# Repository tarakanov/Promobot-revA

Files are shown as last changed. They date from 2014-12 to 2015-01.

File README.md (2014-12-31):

Promobot
=============

Main board for Promobot, robotic platform. Still in development.

Schematic and layout done in Eagle.
Board has four VNH5019A-E H-bridge drivers for high current DC brushed motors, 50W 2ch audio amplifier (TPA116D2), two DC/DC step-up converters (TPS43061, up to 40V, 20A), one DC/DC step-down converter (TPS563200, 5V, 3A) and MCU for control (atmega32u4, Arduino Leonardo compatible).

It is initial design, so the board is big and bulky (15x15 cm). The board is manufactured and tested, but the current and power limits was not reached. There is a lot things to cut. Feel free to ask questions and make improvements.

Designed by Semyon Tarakanov. Creative Commons Attribution, Share-Alike license.

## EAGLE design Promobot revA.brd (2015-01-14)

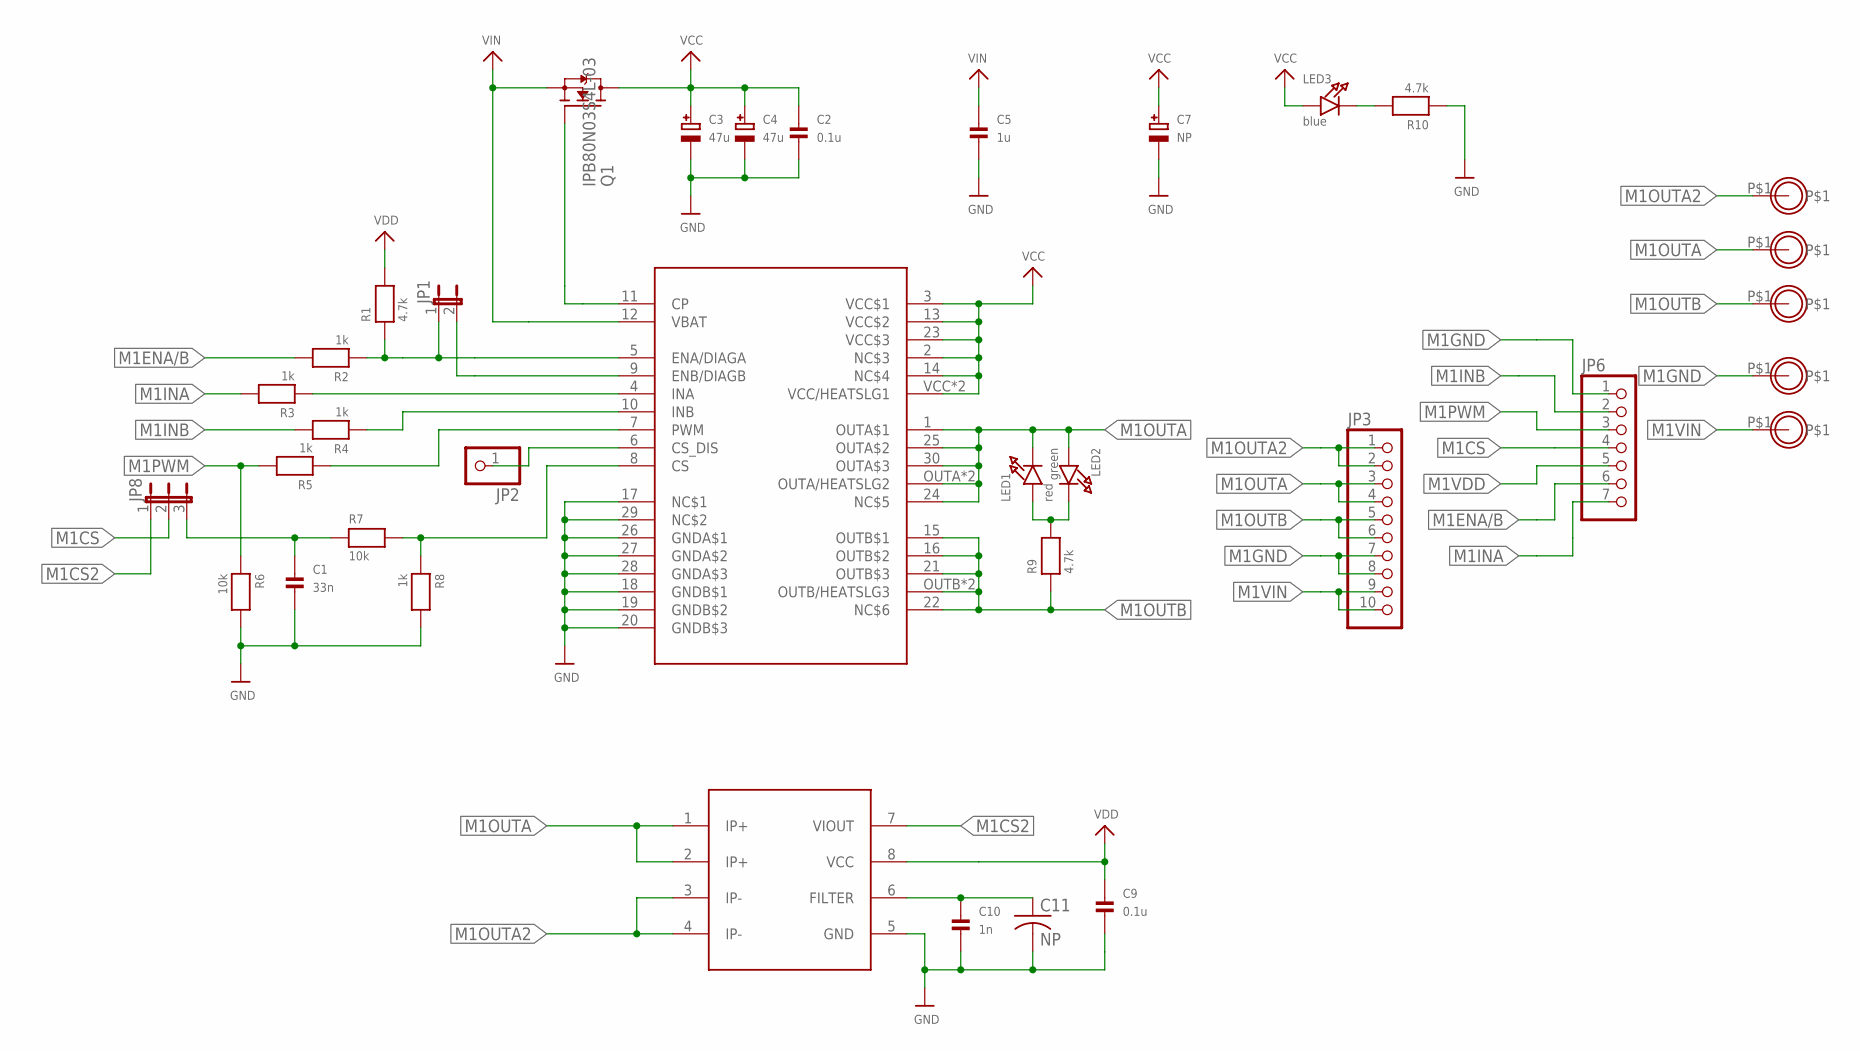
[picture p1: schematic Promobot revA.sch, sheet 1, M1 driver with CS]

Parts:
C1: 33n; _0603
C2, C9: 0.1u; _0603
C3, C4: 47u; PANASONIC_C
C5: 1u; _0805
C7: NP; CELEC_3.5MM_10MM
C10: 1n; _0603
C11: NP; C025-024X044
JP1: JUMPER2
JP2: HEADER-1X1ROUND; 1X01_ROUND
JP3: HEADER-1X10ROUND; 1X10_ROUND
JP6: HEADER-1X7ROUND; 1X07_ROUND
JP8: JUMPER3
LED1: red; CHIPLED_0603
LED2: green; CHIPLED_0603
LED3: blue; CHIPLED_0603
M1OUTA, M1OUTA1, M1OUTA3, M1OUTA4, M1OUTB: MOUNTINGHOLE2.5_THICK; MOUNTINGHOLE_2.5_PLATED_THICK
Q1: IPB80N03S4L-03; TO263
R1, R9, R10: 4.7k; 0603
R2, R3, R4, R5, R8: 1k; 0603
R6, R7: 10k; 0603
U1: VNH5019A-E; MULTIPOWERSO-30
U2: ACS714; SOIC8_208MIL

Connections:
M1CS: JP6.4, JP8.2
M1CS1: C1.1, JP8.3, R7.1
M1CS2: JP8.1, U2.7 (VIOUT)
M1ENA/B: JP6.6, R2.2
M1GND: C1.2, C2.2, C3.-, C4.-, C5.2, C7.-, C9.2, C10.2, C11.2, JP3.7, JP3.8, JP6.1, M1OUTA3.P$1, R6.2, R8.2, R10.1, U1.17 (NC$1), U1.18 (GNDB$1), U1.19 (GNDB$2), U1.20 (GNDB$3), U1.26 (GNDA$1), U1.27 (GNDA$2), U1.28 (GNDA$3), U1.29 (NC$2), U2.5 (GND); also elsewhere on the board
M1INA: JP6.7, R3.2
M1INB: JP6.2, R4.2
M1OUTA: JP3.3, JP3.4, LED1.C, LED2.A, M1OUTA1.P$1, U1.1 (OUTA$1), U1.24 (NC$5), U1.25 (OUTA$2), U1.30 (OUTA$3), U1.OUTA (OUTA/HEATSLG2), U1.OUTA@1 (OUTA/HEATSLG2), U2.1 (IP+), U2.2 (IP+)
M1OUTA2: JP3.1, JP3.2, M1OUTA.P$1, U2.3 (IP-), U2.4 (IP-)
M1OUTB: JP3.5, JP3.6, M1OUTB.P$1, R9.1, U1.15 (OUTB$1), U1.16 (OUTB$2), U1.21 (OUTB$3), U1.22 (NC$6), U1.OUTB (OUTB/HEATSLG3), U1.OUTB@1 (OUTB/HEATSLG3)
M1PWM: JP6.3, R5.2, R6.1
M1VCC: C2.1, C3.+, C4.+, C7.+, LED3.A, Q1.3 (D), U1.2 (NC$3), U1.3 (VCC$1), U1.13 (VCC$2), U1.14 (NC$4), U1.23 (VCC$3), U1.VCC (VCC/HEATSLG1), U1.VCC@1 (VCC/HEATSLG1); also elsewhere on the board
M1VDD: C9.1, JP6.5, R1.2, U2.8 (VCC)
M1VIN: C5.1, JP3.9, JP3.10, M1OUTA4.P$1, Q1.2 (S), U1.12 (VBAT)
unnamed: Q1.1 (G), U1.11 (CP)
unnamed: JP1.2, U1.9 (ENB/DIAGB)
unnamed: R5.1, U1.7 (PWM)
unnamed: JP1.1, R1.1, R2.1, U1.5 (ENA/DIAGA)
unnamed: R7.2, R8.1, U1.8 (CS)
unnamed: R3.1, U1.4 (INA)
unnamed: R4.1, U1.10 (INB)
unnamed: JP2.1, U1.6 (CS_DIS)
unnamed: LED3.C, R10.2
unnamed: C10.1, C11.1, U2.6 (FILTER)
unnamed: LED1.A, LED2.C, R9.2

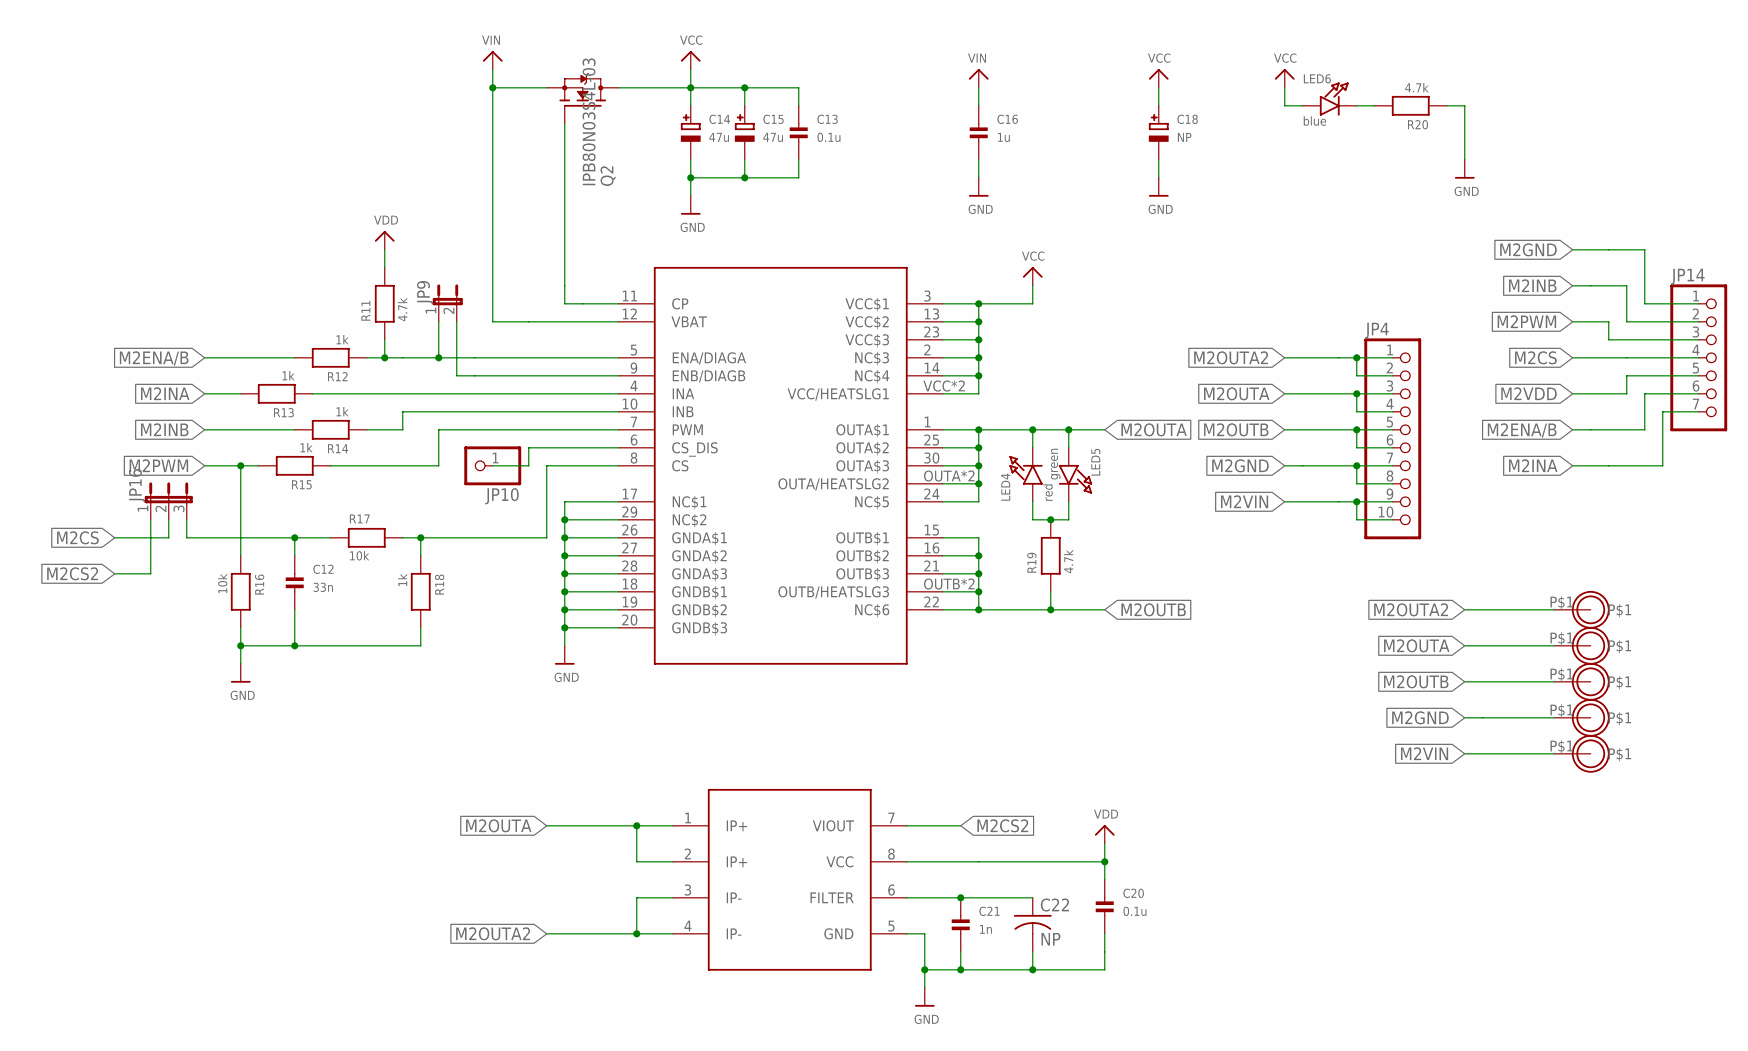
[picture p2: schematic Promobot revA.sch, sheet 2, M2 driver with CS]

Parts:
C12: 33n; _0603
C13, C20: 0.1u; _0603
C14, C15: 47u; PANASONIC_C
C16: 1u; _0805
C18: NP; CELEC_3.5MM_10MM
C21: 1n; _0603
C22: NP; C025-024X044
JP4: HEADER-1X10ROUND; 1X10_ROUND
JP9: JUMPER2
JP10: HEADER-1X1ROUND; 1X01_ROUND
JP14: HEADER-1X7ROUND; 1X07_ROUND
JP16: JUMPER3
LED4: red; CHIPLED_0603
LED5: green; CHIPLED_0603
LED6: blue; CHIPLED_0603
M1OUTA2, M1OUTA5, M1OUTA6, M1OUTA7, M1OUTB1: MOUNTINGHOLE2.5_THICK; MOUNTINGHOLE_2.5_PLATED_THICK
Q2: IPB80N03S4L-03; TO263
R11, R19, R20: 4.7k; 0603
R12, R13, R14, R15, R18: 1k; 0603
R16, R17: 10k; 0603
U3: VNH5019A-E; MULTIPOWERSO-30
U4: ACS714; SOIC8_208MIL

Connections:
M2CS: JP14.4, JP16.2
M2CS2: JP16.1, U4.7 (VIOUT)
M2ENA/B: JP14.6, R12.2
M2GND: C12.2, C13.2, C14.-, C15.-, C16.2, C18.-, C20.2, C21.2, C22.2, JP4.7, JP4.8, JP14.1, M1OUTA6.P$1, R16.2, R18.2, R20.1, U3.17 (NC$1), U3.18 (GNDB$1), U3.19 (GNDB$2), U3.20 (GNDB$3), U3.26 (GNDA$1), U3.27 (GNDA$2), U3.28 (GNDA$3), U3.29 (NC$2), U4.5 (GND); also elsewhere on the board
M2INA: JP14.7, R13.2
M2INB: JP14.2, R14.2
M2OUTA: JP4.3, JP4.4, LED4.C, LED5.A, M1OUTA5.P$1, U3.1 (OUTA$1), U3.24 (NC$5), U3.25 (OUTA$2), U3.30 (OUTA$3), U3.OUTA (OUTA/HEATSLG2), U3.OUTA@1 (OUTA/HEATSLG2), U4.1 (IP+), U4.2 (IP+)
M2OUTA2: JP4.1, JP4.2, M1OUTA2.P$1, U4.3 (IP-), U4.4 (IP-)
M2OUTB: JP4.5, JP4.6, M1OUTB1.P$1, R19.1, U3.15 (OUTB$1), U3.16 (OUTB$2), U3.21 (OUTB$3), U3.22 (NC$6), U3.OUTB (OUTB/HEATSLG3), U3.OUTB@1 (OUTB/HEATSLG3)
M2PWM: JP14.3, R15.2, R16.1
M2VCC: C13.1, C14.+, C15.+, C18.+, LED6.A, Q2.3 (D), U3.2 (NC$3), U3.3 (VCC$1), U3.13 (VCC$2), U3.14 (NC$4), U3.23 (VCC$3), U3.VCC (VCC/HEATSLG1), U3.VCC@1 (VCC/HEATSLG1); also elsewhere on the board
M2VDD: C20.1, JP14.5, R11.2, U4.8 (VCC)
M2VIN: C16.1, JP4.9, JP4.10, M1OUTA7.P$1, Q2.2 (S), U3.12 (VBAT)
unnamed: Q2.1 (G), U3.11 (CP)
unnamed: JP9.1, R11.1, R12.1, U3.5 (ENA/DIAGA)
unnamed: JP9.2, U3.9 (ENB/DIAGB)
unnamed: R13.1, U3.4 (INA)
unnamed: R14.1, U3.10 (INB)
unnamed: R15.1, U3.7 (PWM)
unnamed: R17.2, R18.1, U3.8 (CS)
unnamed: JP10.1, U3.6 (CS_DIS)
unnamed: LED4.A, LED5.C, R19.2
unnamed: LED6.C, R20.2
unnamed: C21.1, C22.1, U4.6 (FILTER)
unnamed: C12.1, JP16.3, R17.1

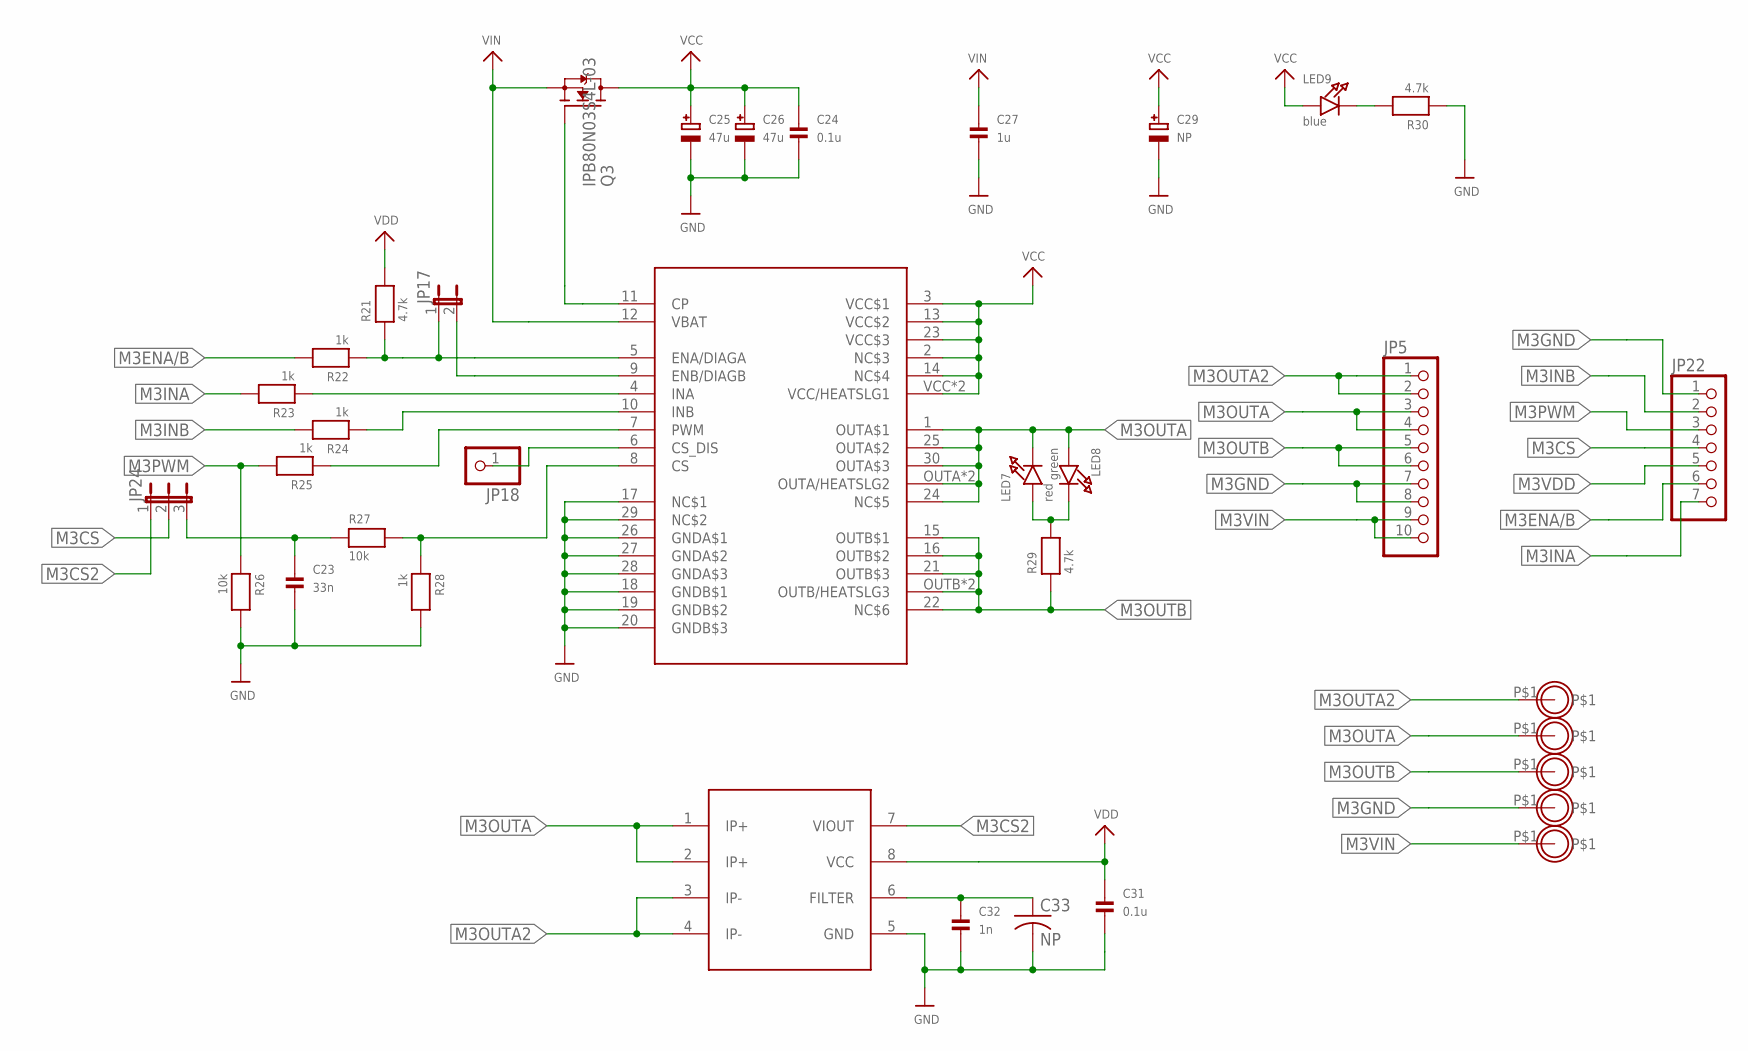
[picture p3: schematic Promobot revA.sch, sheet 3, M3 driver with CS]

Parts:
C23: 33n; _0603
C24, C31: 0.1u; _0603
C25, C26: 47u; PANASONIC_C
C27: 1u; _0805
C29: NP; CELEC_3.5MM_10MM
C32: 1n; _0603
C33: NP; C025-024X044
JP5: HEADER-1X10ROUND; 1X10_ROUND
JP17: JUMPER2
JP18: HEADER-1X1ROUND; 1X01_ROUND
JP22: HEADER-1X7ROUND; 1X07_ROUND
JP24: JUMPER3
LED7: red; CHIPLED_0603
LED8: green; CHIPLED_0603
LED9: blue; CHIPLED_0603
M1OUTA8, M1OUTA9, M1OUTA10, M1OUTA11, M1OUTB2: MOUNTINGHOLE2.5_THICK; MOUNTINGHOLE_2.5_PLATED_THICK
Q3: IPB80N03S4L-03; TO263
R21, R29, R30: 4.7k; 0603
R22, R23, R24, R25, R28: 1k; 0603
R26, R27: 10k; 0603
U5: VNH5019A-E; MULTIPOWERSO-30
U6: ACS714; SOIC8_208MIL

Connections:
M3CS: JP22.4, JP24.2
M3CS2: JP24.1, U6.7 (VIOUT)
M3ENA/B: JP22.6, R22.2
M3GND: C23.2, C24.2, C25.-, C26.-, C27.2, C29.-, C31.2, C32.2, C33.2, JP5.7, JP5.8, JP22.1, M1OUTA10.P$1, R26.2, R28.2, R30.1, U5.17 (NC$1), U5.18 (GNDB$1), U5.19 (GNDB$2), U5.20 (GNDB$3), U5.26 (GNDA$1), U5.27 (GNDA$2), U5.28 (GNDA$3), U5.29 (NC$2), U6.5 (GND); also elsewhere on the board
M3INA: JP22.7, R23.2
M3INB: JP22.2, R24.2
M3OUTA: JP5.3, JP5.4, LED7.C, LED8.A, M1OUTA9.P$1, U5.1 (OUTA$1), U5.24 (NC$5), U5.25 (OUTA$2), U5.30 (OUTA$3), U5.OUTA (OUTA/HEATSLG2), U5.OUTA@1 (OUTA/HEATSLG2), U6.1 (IP+), U6.2 (IP+)
M3OUTA2: JP5.1, JP5.2, M1OUTA8.P$1, U6.3 (IP-), U6.4 (IP-)
M3OUTB: JP5.5, JP5.6, M1OUTB2.P$1, R29.1, U5.15 (OUTB$1), U5.16 (OUTB$2), U5.21 (OUTB$3), U5.22 (NC$6), U5.OUTB (OUTB/HEATSLG3), U5.OUTB@1 (OUTB/HEATSLG3)
M3PWM: JP22.3, R25.2, R26.1
M3VCC: C24.1, C25.+, C26.+, C29.+, LED9.A, Q3.3 (D), U5.2 (NC$3), U5.3 (VCC$1), U5.13 (VCC$2), U5.14 (NC$4), U5.23 (VCC$3), U5.VCC (VCC/HEATSLG1), U5.VCC@1 (VCC/HEATSLG1); also elsewhere on the board
M3VDD: C31.1, JP22.5, R21.2, U6.8 (VCC)
M3VIN: C27.1, JP5.9, JP5.10, M1OUTA11.P$1, Q3.2 (S), U5.12 (VBAT)
unnamed: Q3.1 (G), U5.11 (CP)
unnamed: JP17.1, R21.1, R22.1, U5.5 (ENA/DIAGA)
unnamed: JP17.2, U5.9 (ENB/DIAGB)
unnamed: R23.1, U5.4 (INA)
unnamed: R24.1, U5.10 (INB)
unnamed: R25.1, U5.7 (PWM)
unnamed: R27.2, R28.1, U5.8 (CS)
unnamed: JP18.1, U5.6 (CS_DIS)
unnamed: LED7.A, LED8.C, R29.2
unnamed: LED9.C, R30.2
unnamed: C32.1, C33.1, U6.6 (FILTER)
unnamed: C23.1, JP24.3, R27.1

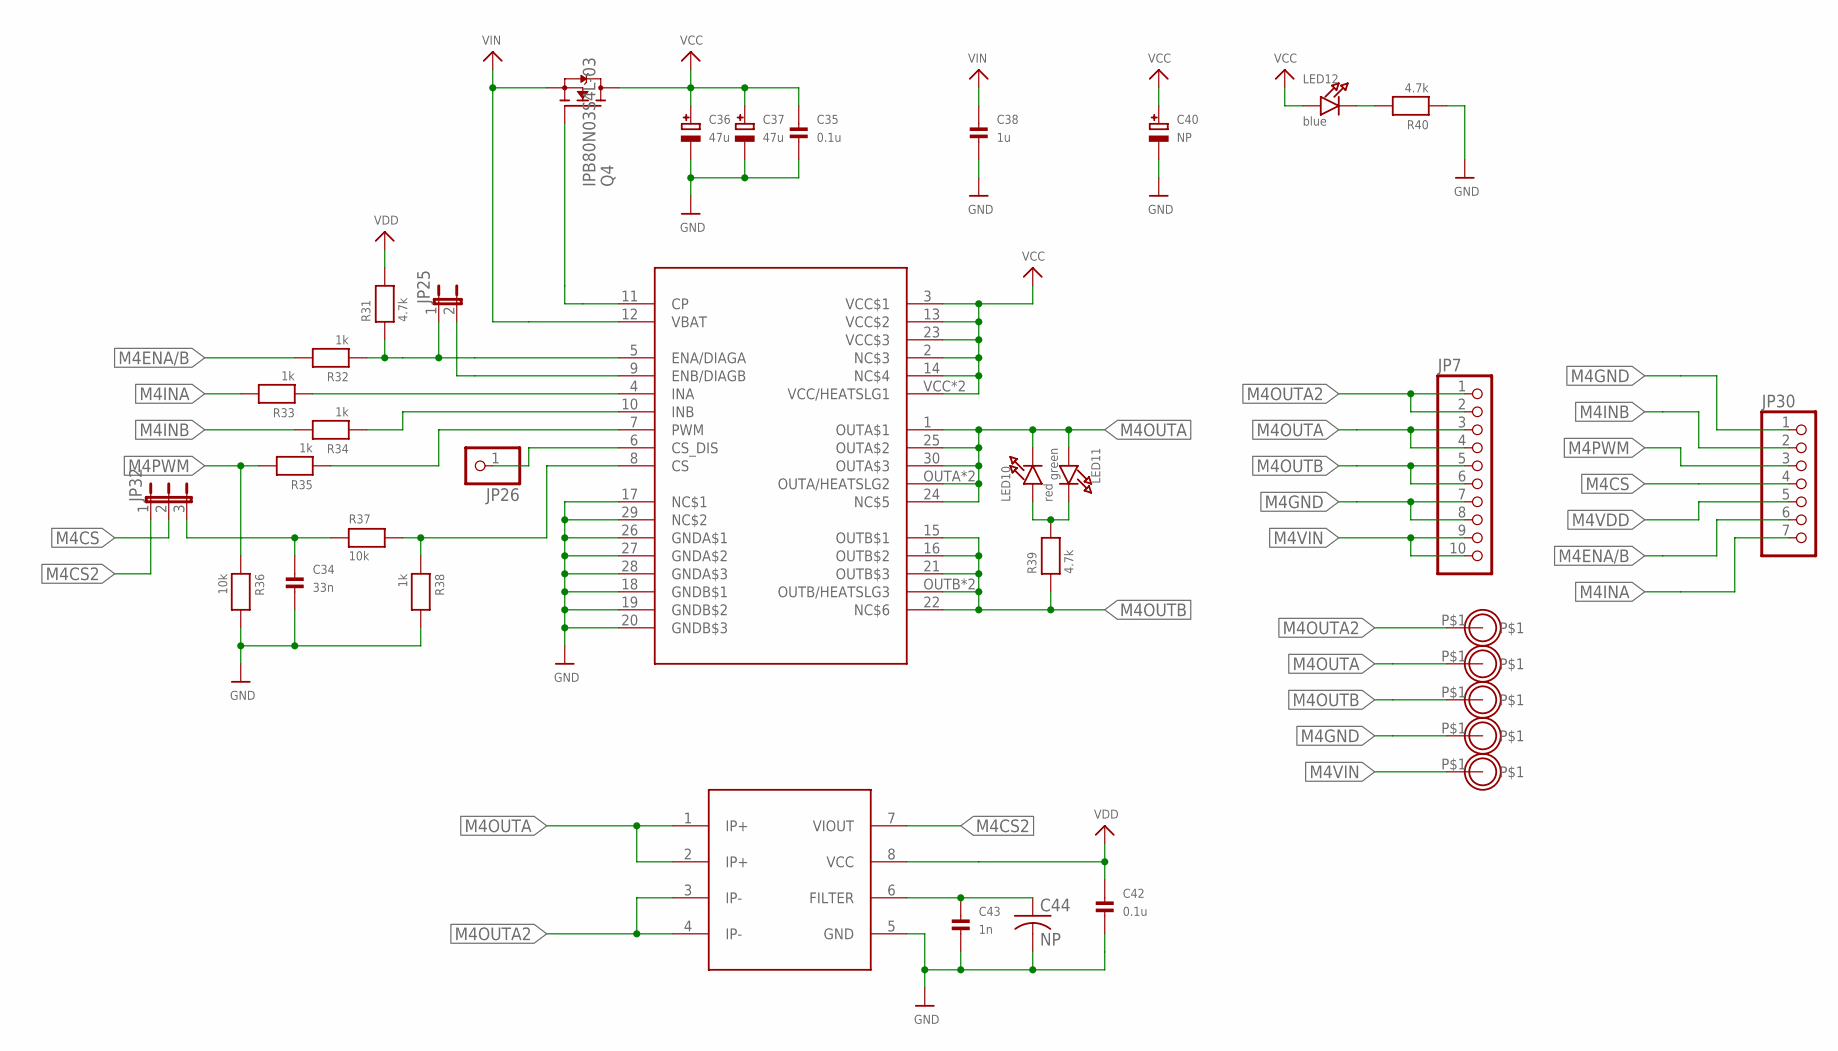
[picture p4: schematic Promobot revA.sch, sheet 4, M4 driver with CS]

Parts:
C34: 33n; _0603
C35, C42: 0.1u; _0603
C36, C37: 47u; PANASONIC_C
C38: 1u; _0805
C40: NP; CELEC_3.5MM_10MM
C43: 1n; _0603
C44: NP; C025-024X044
JP7: HEADER-1X10ROUND; 1X10_ROUND
JP25: JUMPER2
JP26: HEADER-1X1ROUND; 1X01_ROUND
JP30: HEADER-1X7ROUND; 1X07_ROUND
JP32: JUMPER3
LED10: red; CHIPLED_0603
LED11: green; CHIPLED_0603
LED12: blue; CHIPLED_0603
M1OUTA12, M1OUTA13, M1OUTA14, M1OUTA15, M1OUTB3: MOUNTINGHOLE2.5_THICK; MOUNTINGHOLE_2.5_PLATED_THICK
Q4: IPB80N03S4L-03; TO263
R31, R39, R40: 4.7k; 0603
R32, R33, R34, R35, R38: 1k; 0603
R36, R37: 10k; 0603
U7: VNH5019A-E; MULTIPOWERSO-30
U8: ACS714; SOIC8_208MIL

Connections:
M4CS: JP30.4, JP32.2
M4CS2: JP32.1, U8.7 (VIOUT)
M4ENA/B: JP30.6, R32.2
M4GND: C34.2, C35.2, C36.-, C37.-, C38.2, C40.-, C42.2, C43.2, C44.2, JP7.7, JP7.8, JP30.1, M1OUTA14.P$1, R36.2, R38.2, R40.1, U7.17 (NC$1), U7.18 (GNDB$1), U7.19 (GNDB$2), U7.20 (GNDB$3), U7.26 (GNDA$1), U7.27 (GNDA$2), U7.28 (GNDA$3), U7.29 (NC$2), U8.5 (GND); also elsewhere on the board
M4INA: JP30.7, R33.2
M4INB: JP30.2, R34.2
M4OUTA: JP7.3, JP7.4, LED10.C, LED11.A, M1OUTA13.P$1, U7.1 (OUTA$1), U7.24 (NC$5), U7.25 (OUTA$2), U7.30 (OUTA$3), U7.OUTA (OUTA/HEATSLG2), U7.OUTA@1 (OUTA/HEATSLG2), U8.1 (IP+), U8.2 (IP+)
M4OUTA2: JP7.1, JP7.2, M1OUTA12.P$1, U8.3 (IP-), U8.4 (IP-)
M4OUTB: JP7.5, JP7.6, M1OUTB3.P$1, R39.1, U7.15 (OUTB$1), U7.16 (OUTB$2), U7.21 (OUTB$3), U7.22 (NC$6), U7.OUTB (OUTB/HEATSLG3), U7.OUTB@1 (OUTB/HEATSLG3)
M4PWM: JP30.3, R35.2, R36.1
M4VCC: C35.1, C36.+, C37.+, C40.+, LED12.A, Q4.3 (D), U7.2 (NC$3), U7.3 (VCC$1), U7.13 (VCC$2), U7.14 (NC$4), U7.23 (VCC$3), U7.VCC (VCC/HEATSLG1), U7.VCC@1 (VCC/HEATSLG1); also elsewhere on the board
M4VDD: C42.1, JP30.5, R31.2, U8.8 (VCC)
M4VIN: C38.1, JP7.9, JP7.10, M1OUTA15.P$1, Q4.2 (S), U7.12 (VBAT)
unnamed: Q4.1 (G), U7.11 (CP)
unnamed: JP25.1, R31.1, R32.1, U7.5 (ENA/DIAGA)
unnamed: JP25.2, U7.9 (ENB/DIAGB)
unnamed: R33.1, U7.4 (INA)
unnamed: R34.1, U7.10 (INB)
unnamed: R35.1, U7.7 (PWM)
unnamed: R37.2, R38.1, U7.8 (CS)
unnamed: JP26.1, U7.6 (CS_DIS)
unnamed: LED10.A, LED11.C, R39.2
unnamed: LED12.C, R40.2
unnamed: C43.1, C44.1, U8.6 (FILTER)
unnamed: C34.1, JP32.3, R37.1

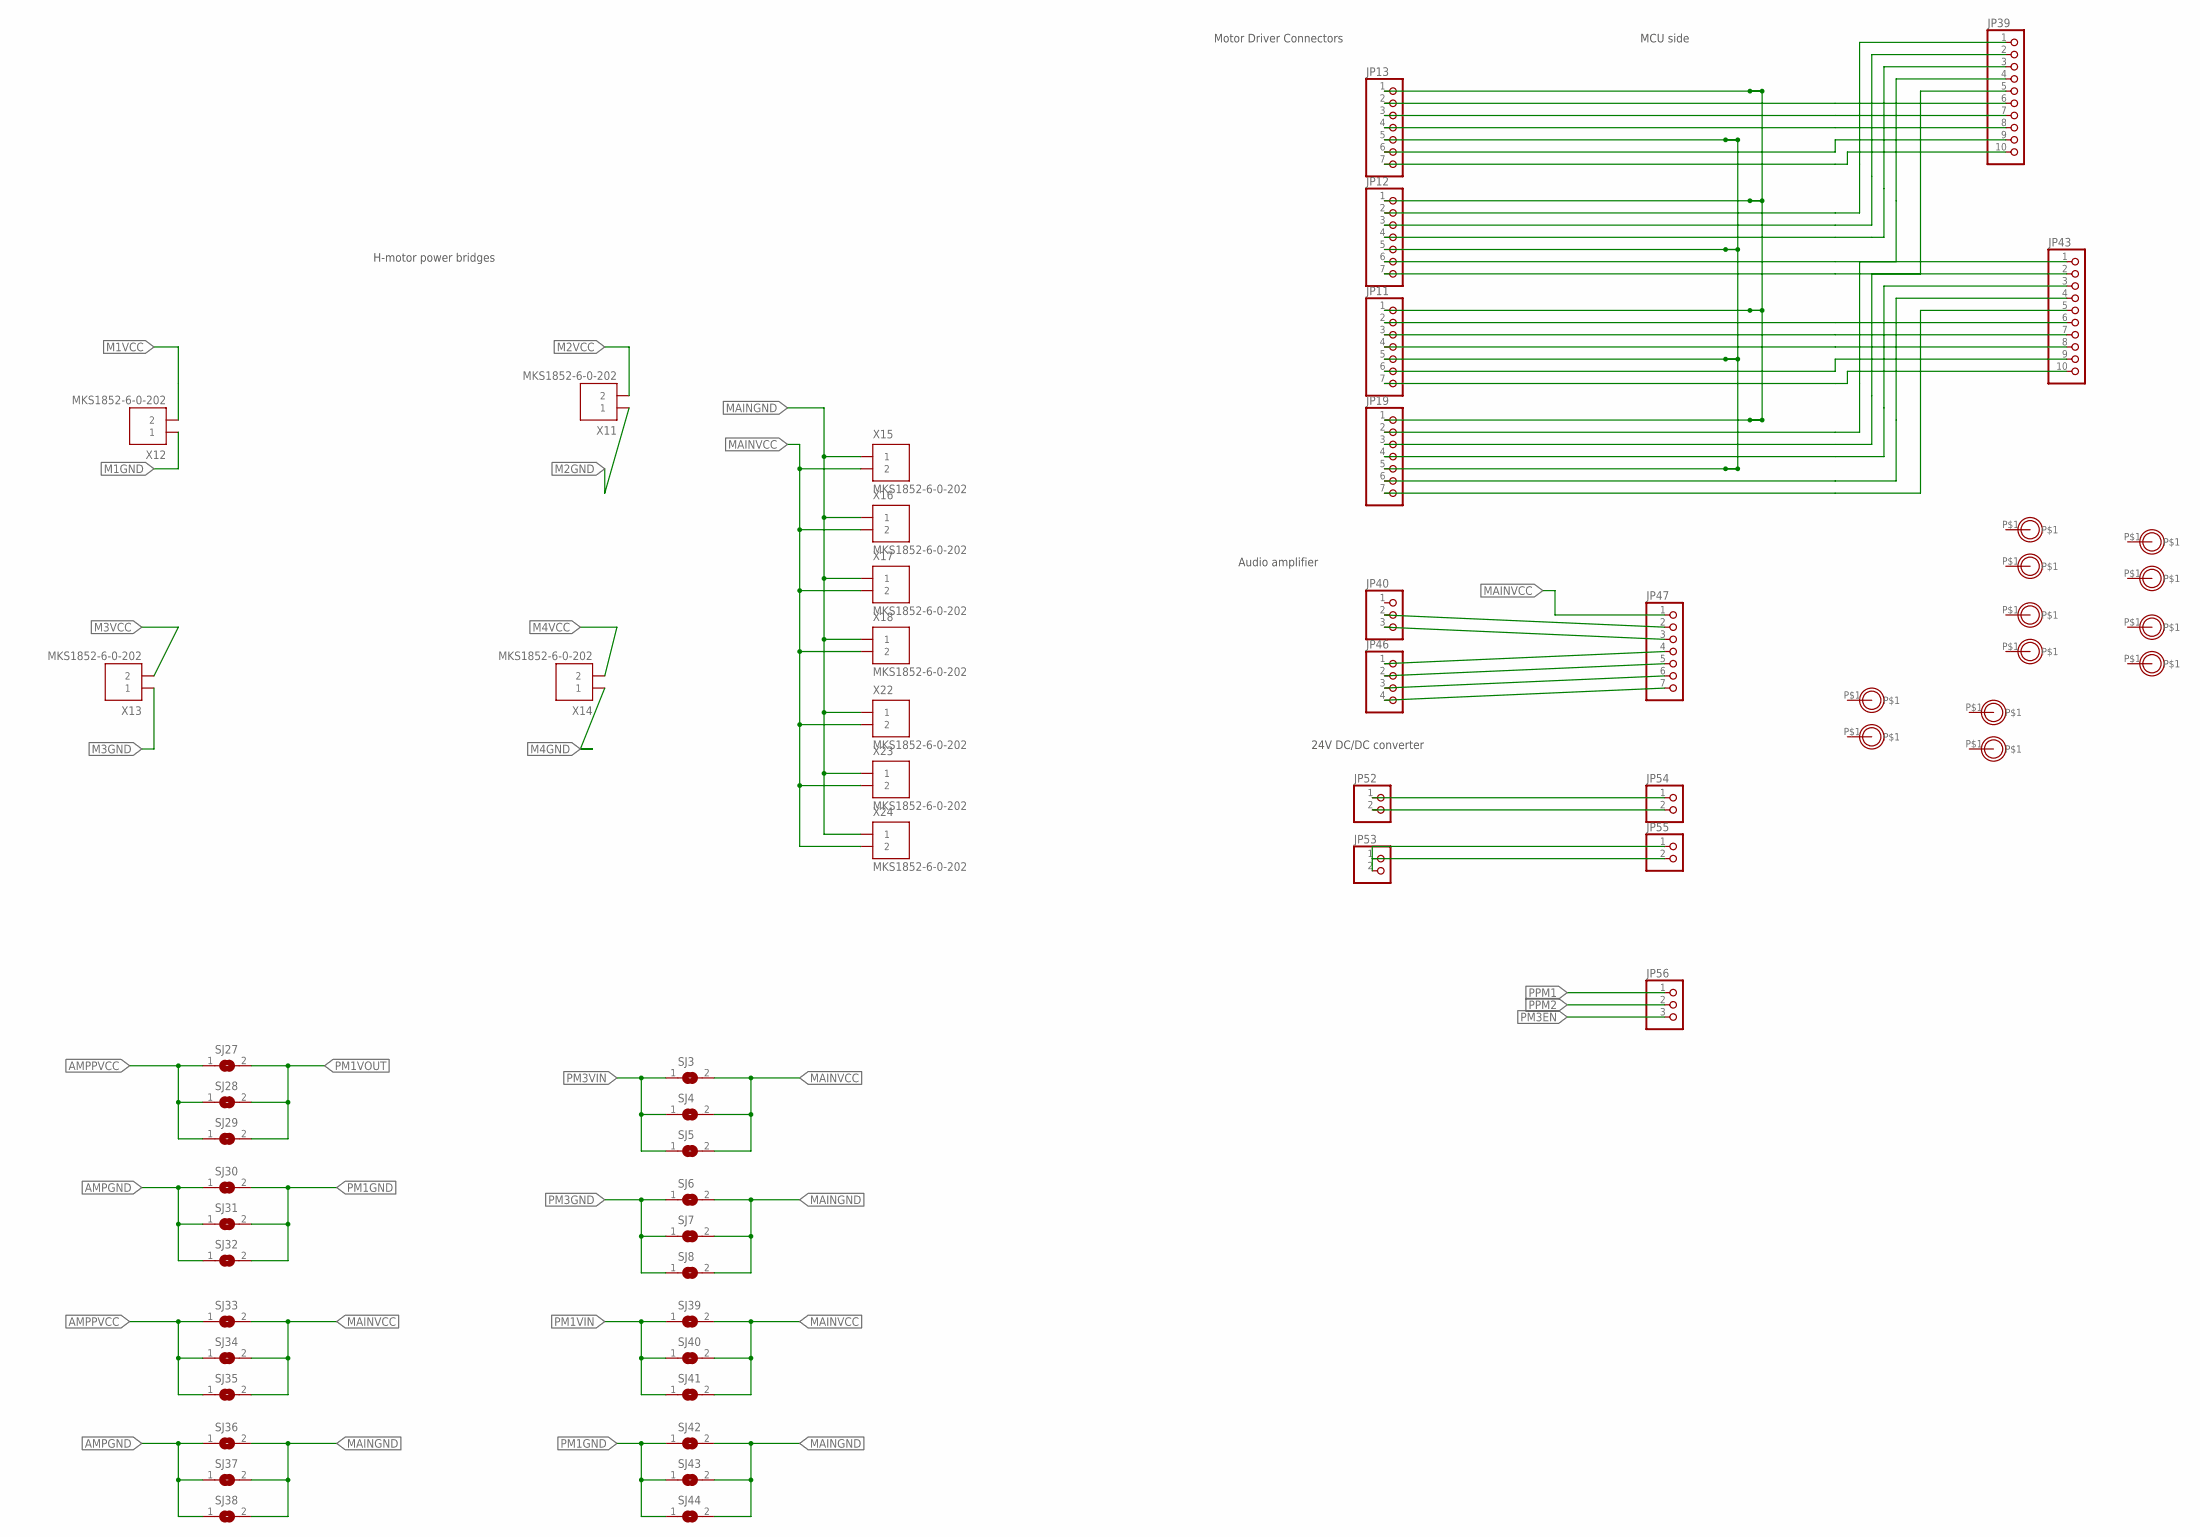
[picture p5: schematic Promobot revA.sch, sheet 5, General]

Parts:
JP11, JP12, JP13, JP19, JP47: HEADER-1X7ROUND; 1X07_ROUND
JP39, JP43: HEADER-1X1070MIL; 1X10_ROUND70
JP40: HEADER-1X376MIL; 1X03_ROUND_76
JP46: HEADER-1X476MIL; 1X04_ROUND_76
JP52, JP53, JP54, JP55: HEADER-1X2ROUND; 1X02_ROUND
JP56: HEADER-1X3ROUND; 1X03_ROUND
M1OUTA16, M1OUTA17, M1OUTA18, M1OUTA19, M1OUTA20, M1OUTA21, M1OUTA22, M1OUTA23, M1OUTA24, M1OUTA25, M1OUTB4, M1OUTB5: MOUNTINGHOLE2.5_THICK; MOUNTINGHOLE_2.5_PLATED_THICK
SJ3, SJ4, SJ5, SJ6, SJ7, SJ8, SJ27, SJ28, SJ29, SJ30, SJ31, SJ32, SJ33, SJ34, SJ35, SJ36, SJ37, SJ38, SJ39, SJ40, SJ41, SJ42, SJ43, SJ44: SOLDERJUMPER; SOLDERJUMPER_ARROW_NOPASTE
X11, X12, X13, X14, X15, X16, X17, X18, X22, X23, X24: MKS1852-6-0-202

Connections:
AMPGND: SJ30.1, SJ31.1, SJ32.1, SJ36.1, SJ37.1, SJ38.1; also elsewhere on the board
AMPPVCC: SJ27.1, SJ28.1, SJ29.1, SJ33.1, SJ34.1, SJ35.1; also elsewhere on the board
M1GND: X12.1; also elsewhere on the board
M1VCC: X12.2; also elsewhere on the board
M2GND: X11.1; also elsewhere on the board
M2VCC: X11.2; also elsewhere on the board
M3GND: X13.1; also elsewhere on the board
M3VCC: X13.2; also elsewhere on the board
M4GND: X14.1; also elsewhere on the board
M4VCC: X14.2; also elsewhere on the board
MAINGND: JP11.1, JP12.1, JP13.1, JP19.1, SJ6.2, SJ7.2, SJ8.2, SJ36.2, SJ37.2, SJ38.2, SJ42.2, SJ43.2, SJ44.2, X15.1, X16.1, X17.1, X18.1, X22.1, X23.1, X24.1
MAINVCC: JP11.5, JP12.5, JP13.5, JP19.5, JP47.1, SJ3.2, SJ4.2, SJ5.2, SJ33.2, SJ34.2, SJ35.2, SJ39.2, SJ40.2, SJ41.2, X15.2, X16.2, X17.2, X18.2, X22.2, X23.2, X24.2
unnamed: JP52.1, JP54.1
unnamed: JP52.2, JP54.2
unnamed: JP13.2, JP39.6
unnamed: JP13.3, JP39.7
unnamed: JP13.4, JP39.8
unnamed: JP40.2, JP47.2
unnamed: JP13.6, JP39.9
unnamed: JP13.7, JP39.10
unnamed: JP12.2, JP39.1
unnamed: JP12.3, JP39.2
unnamed: JP12.4, JP39.3
unnamed: JP12.6, JP39.4
unnamed: JP12.7, JP39.5
unnamed: JP40.3, JP47.3
unnamed: JP11.2, JP43.6
unnamed: JP11.3, JP43.7
unnamed: JP11.4, JP43.8
unnamed: JP46.1, JP47.4
unnamed: JP11.6, JP43.9
unnamed: JP11.7, JP43.10
unnamed: JP46.2, JP47.5
unnamed: JP19.2, JP43.1
unnamed: JP19.3, JP43.2
unnamed: JP19.4, JP43.3
unnamed: JP46.3, JP47.6
unnamed: JP19.6, JP43.4
unnamed: JP19.7, JP43.5
unnamed: JP46.4, JP47.7
unnamed: JP53.1, JP55.1
unnamed: JP53.2, JP55.2
PM1GND: SJ30.2, SJ31.2, SJ32.2, SJ42.1, SJ43.1, SJ44.1; also elsewhere on the board
PM1VIN: SJ39.1, SJ40.1, SJ41.1; also elsewhere on the board
PM1VOUT: SJ27.2, SJ28.2, SJ29.2; also elsewhere on the board
PM3EN: JP56.3; also elsewhere on the board
PM3GND: SJ6.1, SJ7.1, SJ8.1; also elsewhere on the board
PM3VIN: SJ3.1, SJ4.1, SJ5.1; also elsewhere on the board
PPM1: JP56.1; also elsewhere on the board
PPM2: JP56.2; also elsewhere on the board

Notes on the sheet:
Motor Driver Connectors
MCU side
Audio amplifier
24V DC/DC converter
H-motor power bridges

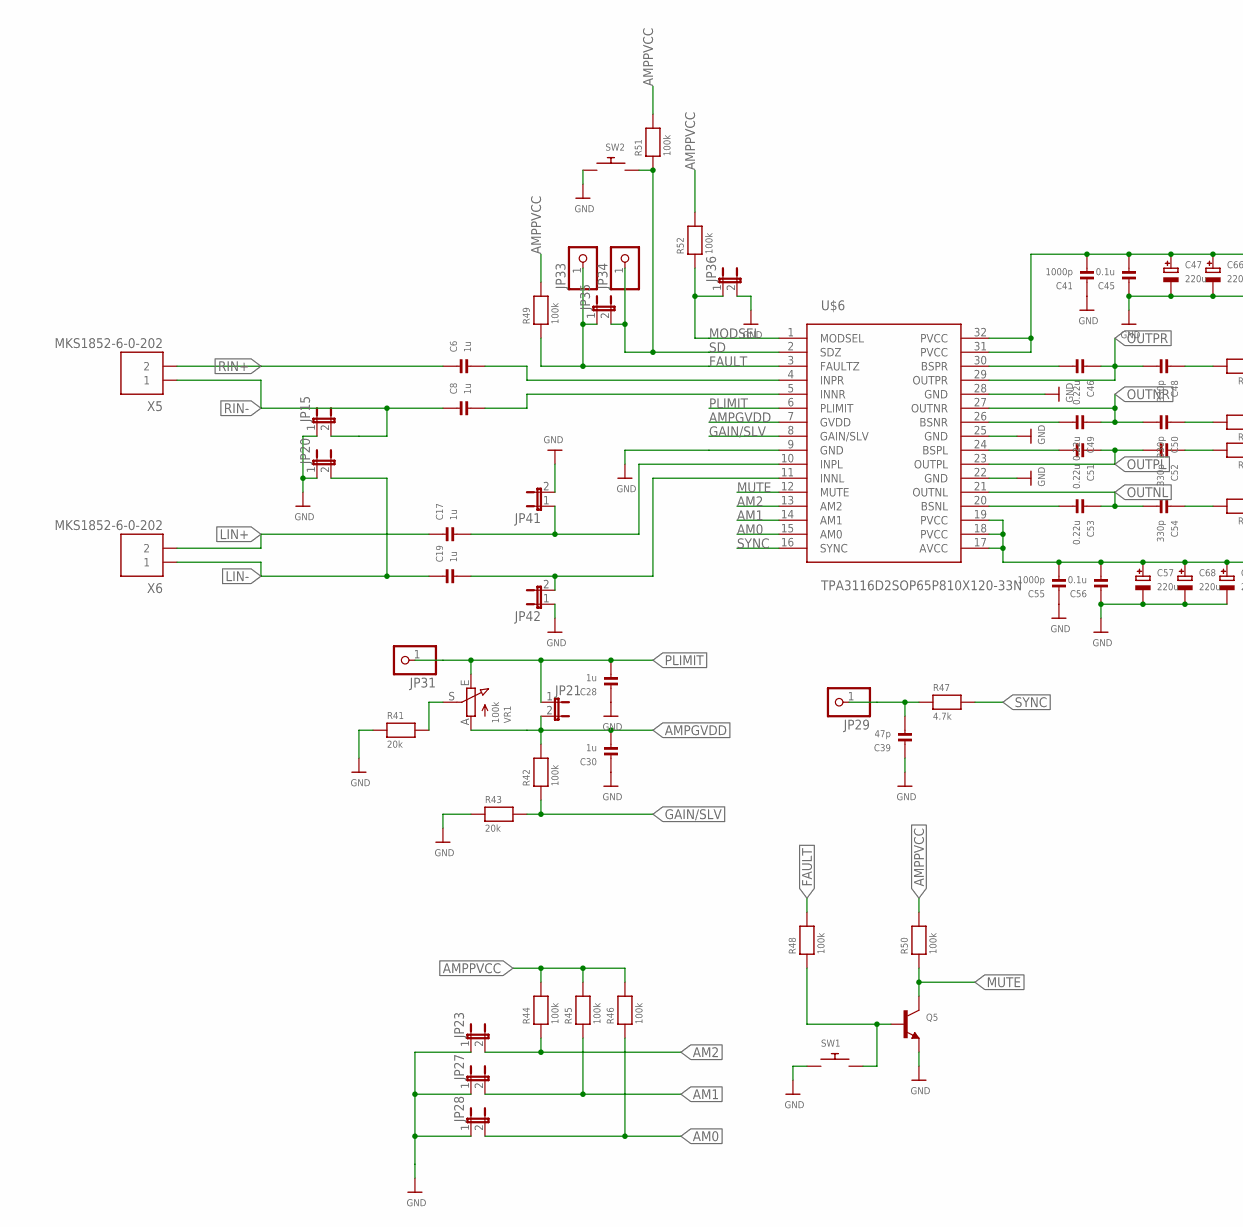
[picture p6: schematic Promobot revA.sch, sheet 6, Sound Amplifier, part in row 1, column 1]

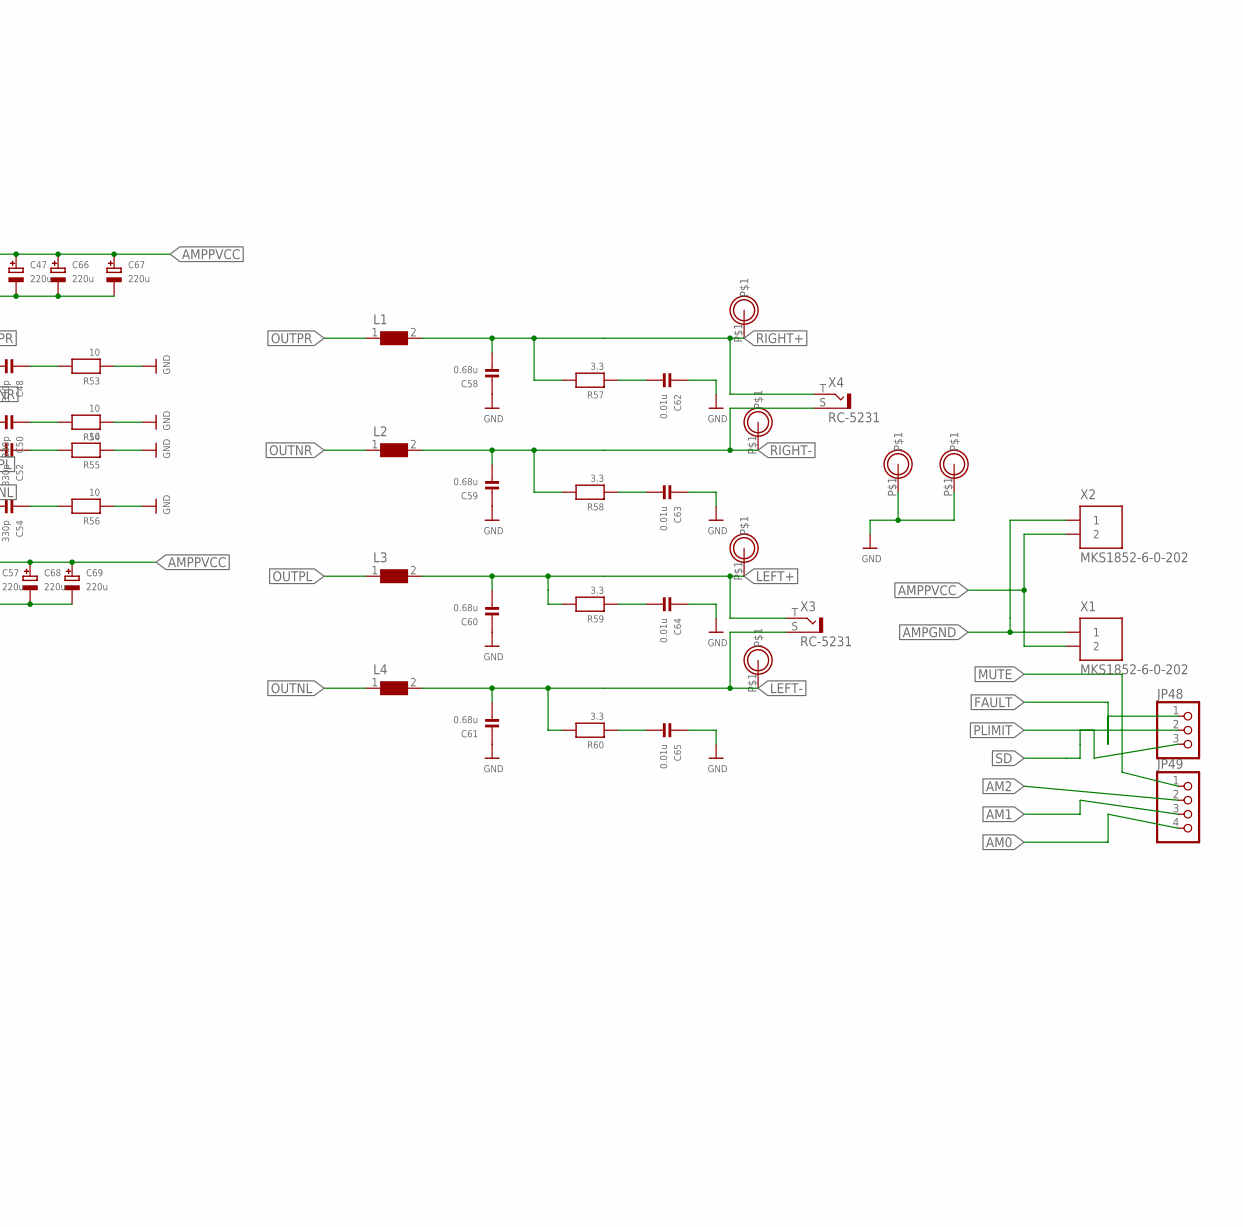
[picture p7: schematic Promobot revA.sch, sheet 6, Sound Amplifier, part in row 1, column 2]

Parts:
C6, C8, C17, C19: 1u; _0603
C28, C30: 1u; _0603MP
C39: 47p; _0603
C41, C55: 1000p; _0603
C45, C56: 0.1u; _0603
C46, C49, C51, C53: 0.22u; _0603
C47, C57, C66, C67, C68, C69: 220u; CELEC_3.5MM_10MM
C48, C50, C52, C54: 330p; _0603
C58, C59, C60, C61: 0.68u; 1206
C62, C63, C64, C65: 0.01u; _0805
JP15, JP20, JP21, JP23, JP27, JP28, JP35, JP36, JP41, JP42: JUMPER2
JP29, JP31, JP33, JP34: HEADER-1X1ROUND; 1X01_ROUND
JP48: HEADER-1X376MIL; 1X03_ROUND_76
JP49: HEADER-1X476MIL; 1X04_ROUND_76
L1, L2, L3, L4: WE-PD-7447709100_1260/1245/1280/1210; WE-PD_1260/1245/1280/1210
Q5: TRANSISTOR_NPNWAVE; SOT23-W
R41: 20k; 0603
R42: 100k; _0805
R43: 20k; _0805
R44, R45, R46, R48, R49, R50, R51, R52: 100k; 0603
R47: 4.7k; 0603
R53, R54, R55, R56: 10; 1206
R57, R58, R59, R60: 3.3; _0603
SW1, SW2: SWITCH_PUSHBUTTONSOFTTOUCHSMD_SJ; PUSHBUTTON_SMD_SJ
U$6: TPA3116D2SOP65P810X120-33N; SOP65P810X120-33N
U$81, U$82, U$83, U$84, U$89, U$90: MOUNTINGHOLE; MOUNTINGHOLE_3.0_PLATED
VR1: 100k; TRIMPOT_BOURNS3MM
X1, X2, X5, X6: MKS1852-6-0-202
X3, X4: RC-5231

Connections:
AM0: JP28.2, JP49.4, R46.1, U$6.15 (AM0)
AM1: JP27.2, JP49.3, R45.1, U$6.14 (AM1)
AM2: JP23.2, JP49.2, R44.1, U$6.13 (AM2)
AMPGND: C28.1, C30.1, C39.1, C41.1, C45.1, C47.-, C55.1, C56.1, C57.-, C58.1, C59.1, C60.1, C61.1, C62.1, C63.1, C64.1, C65.1, C66.-, C67.-, C68.-, C69.-, JP15.1, JP20.1, JP23.1, JP27.1, JP28.1, JP36.2, JP41.2, JP42.1, Q5.2 (E), R41.1, R43.1, R53.1, R54.1, R55.1, R56.1, SW1.P$1, SW2.P$2, U$6.9 (GND), U$6.22 (GND), U$6.25 (GND), U$6.28 (GND), U$89.P$1, U$90.P$1, X1.1, X2.1; also elsewhere on the board
AMPGVDD: C30.2, JP21.2, R42.2, U$6.7 (GVDD), VR1.A
AMPPVCC: C41.2, C45.2, C47.+, C55.2, C56.2, C57.+, C66.+, C67.+, C68.+, C69.+, R44.2, R45.2, R46.2, R49.2, R50.2, R51.2, R52.2, U$6.17 (AVCC), U$6.18 (PVCC), U$6.19 (PVCC), U$6.31 (PVCC), U$6.32 (PVCC), X1.2, X2.2; also elsewhere on the board
FAULT: JP33.1, JP35.1, JP48.1, R48.2, R49.1, U$6.3 (FAULTZ)
GAIN/SLV: R42.1, R43.2, U$6.8 (GAIN/SLV)
LEFT+: C60.2, L3.2, R59.2, U$83.P$1, X3.T
LEFT-: C61.2, L4.2, R60.2, U$84.P$1, X3.S
LIN+: C17.1, X6.2
LIN-: C19.1, JP20.2, X6.1
MODSEL: JP36.1, R52.1, U$6.1 (MODSEL)
MUTE: JP49.1, Q5.3 (C), R50.1, U$6.12 (MUTE)
unnamed: R41.2, VR1.S
unnamed: C39.2, JP29.1, R47.1
unnamed: Q5.1 (B), R48.1, SW1.P$2
unnamed: C6.2, U$6.4 (INPR)
unnamed: C8.2, U$6.5 (INNR)
unnamed: C46.2, U$6.30 (BSPR)
unnamed: C48.1, R53.2
unnamed: C17.2, JP41.1, U$6.10 (INPL)
unnamed: C19.2, JP42.2, U$6.11 (INNL)
unnamed: C51.2, U$6.24 (BSPL)
unnamed: C49.2, U$6.26 (BSNR)
unnamed: C50.1, R54.2
unnamed: C65.2, R60.1
unnamed: C52.1, R55.2
unnamed: C62.2, R57.1
unnamed: C53.2, U$6.20 (BSNL)
unnamed: C63.2, R58.1
unnamed: C54.1, R56.2
unnamed: C64.2, R59.1
OUTNL: C53.1, C54.2, L4.1, U$6.21 (OUTNL)
OUTNR: C49.1, C50.2, L2.1, U$6.27 (OUTNR)
OUTPL: C51.1, C52.2, L3.1, U$6.23 (OUTPL)
OUTPR: C46.1, C48.2, L1.1, U$6.29 (OUTPR)
PLIMIT: C28.2, JP21.1, JP31.1, JP48.3, U$6.6 (PLIMIT), VR1.E
RIGHT+: C58.2, L1.2, R57.2, U$81.P$1, X4.T
RIGHT-: C59.2, L2.2, R58.2, U$82.P$1, X4.S
RIN+: C6.1, X5.2
RIN-: C8.1, JP15.2, X5.1
SD: JP34.1, JP35.2, JP48.2, R51.1, SW2.P$1, U$6.2 (SDZ)
SYNC: R47.2, U$6.16 (SYNC)

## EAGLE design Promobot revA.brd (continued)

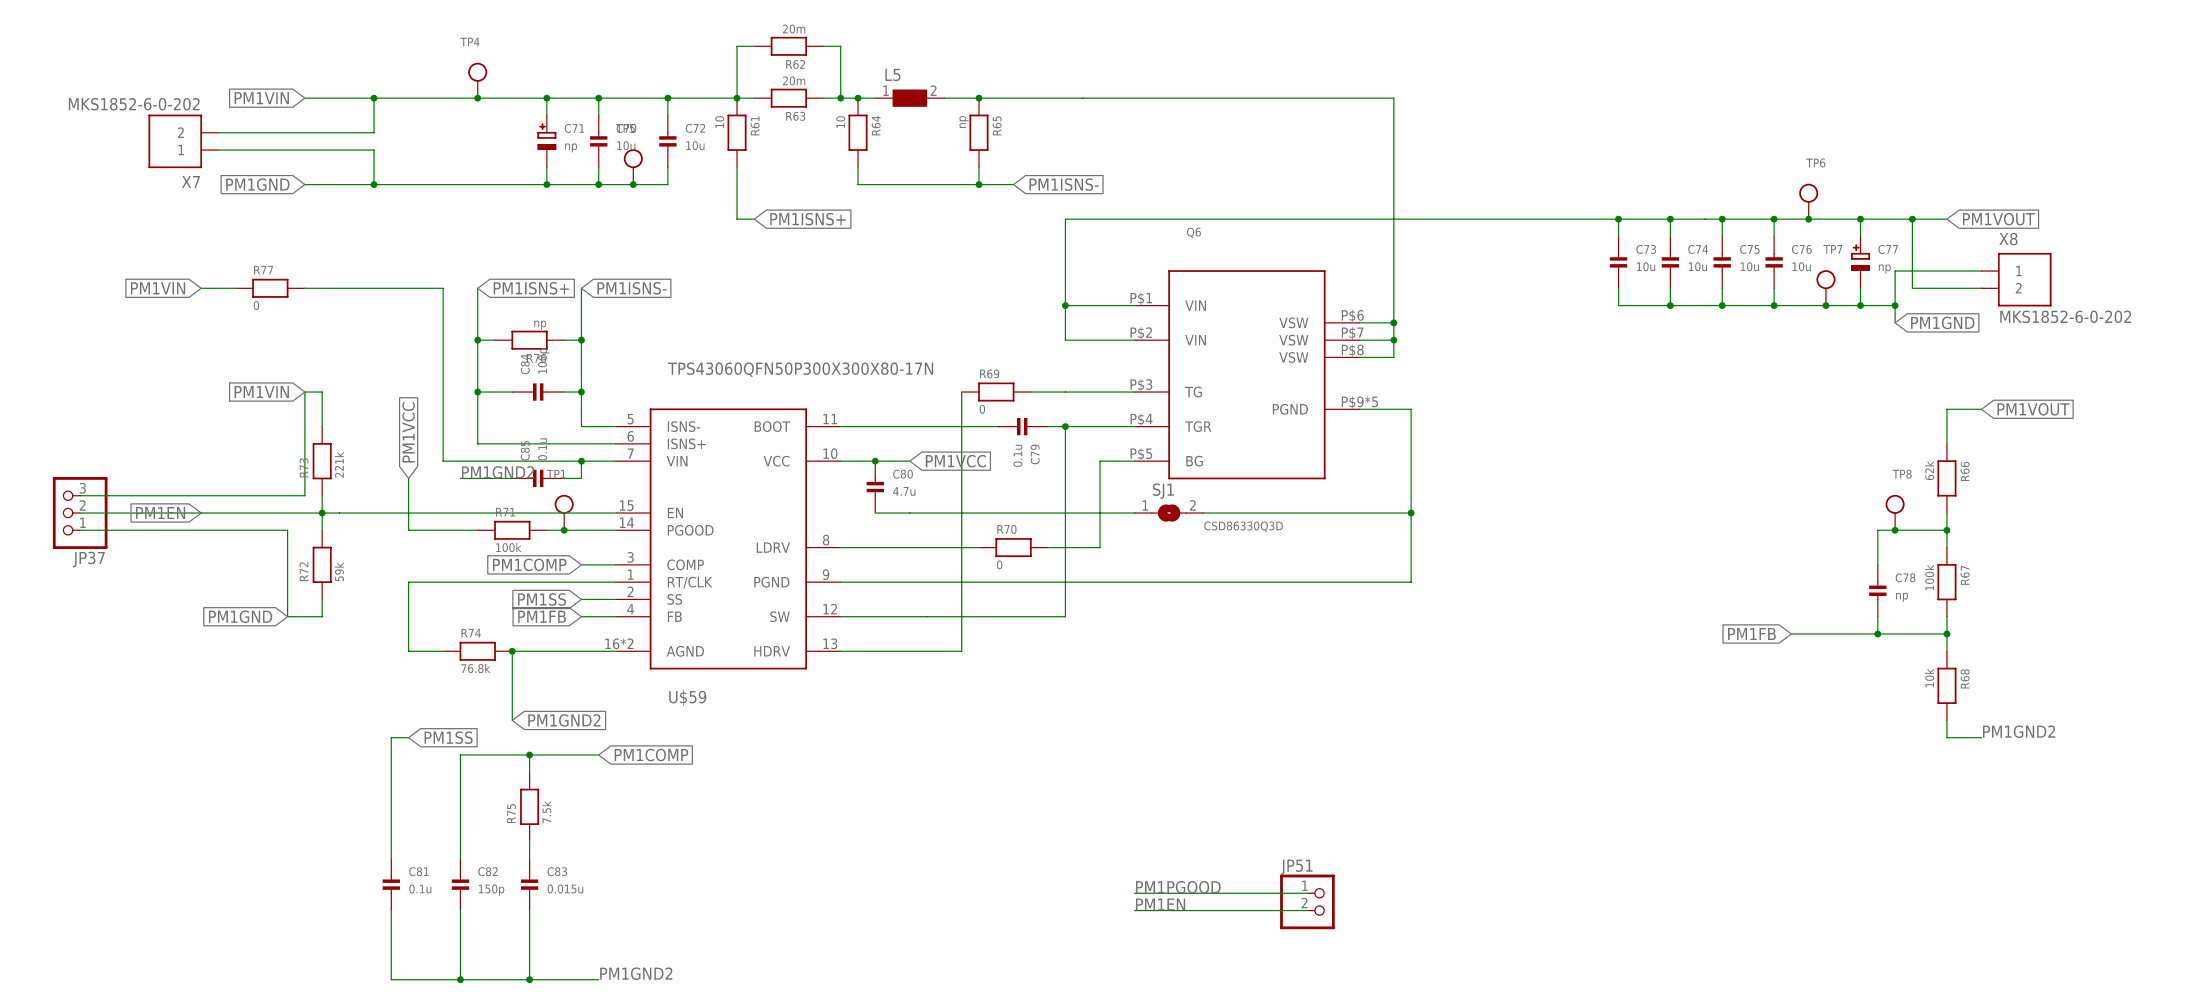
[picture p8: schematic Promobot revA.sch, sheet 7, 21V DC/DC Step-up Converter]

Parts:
C70, C72, C73, C74, C75, C76: 10u; 1206
C71, C77: np; CELEC_3.5MM_10MM
C78: np; _0603
C79, C81: 0.1u; _0603
C80: 4.7u; _0603
C82: 150p; _0603
C83: 0.015u; _0603
C84: 100p; _0603MP
C85: 0.1u; _0603MP
JP37: HEADER-1X376MIL; 1X03_ROUND_76
JP51: HEADER-1X2ROUND; 1X02_ROUND
L5: WE-HCI-744311330_7030/7040/7050; WE-HCI_7030/7040/7050
Q6: CSD86330Q3D; SON330X330
R61, R64: 10; _0603MP
R62, R63: 20m; 1206
R65, R76: np; _0603MP
R66: 62k; 0603
R67, R71: 100k; 0603
R68: 10k; 0603
R69, R70, R77: 0; 0603
R72: 59k; 0603
R73: 221k; 0603
R74: 76.8k; 0603
R75: 7.5k; 0603
SJ1: SOLDERJUMPER; SOLDERJUMPER_ARROW_NOPASTE
TP1, TP4, TP5, TP6, TP7, TP8: TESTPOINT0.1"; 1X01_ROUND
U$59: TPS43060QFN50P300X300X80-17N; QFN50P300X300X80-17N
X7, X8: MKS1852-6-0-202

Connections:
unnamed: L5.1, R62.1, R63.1, R64.1
unnamed: L5.2, Q6.P$6 (VSW), Q6.P$7 (VSW), Q6.P$8 (VSW), R65.1
unnamed: C78.1, R66.2, R67.1, TP8.1
unnamed: Q6.P$3 (TG), R69.2
unnamed: R69.1, U$59.13 (HDRV)
unnamed: C79.1, Q6.P$4 (TGR), U$59.12 (SW)
unnamed: C79.2, U$59.11 (BOOT)
unnamed: R70.1, U$59.8 (LDRV)
unnamed: Q6.P$5 (BG), R70.2
unnamed: R74.1, U$59.1 (RT/CLK)
unnamed: C83.1, R75.1
unnamed: C85.2, R77.2, U$59.7 (VIN)
PM1COMP: C82.1, R75.2, U$59.3 (COMP)
PM1EN: JP37.2, JP51.2, R72.2, R73.1, U$59.15 (EN)
PM1FB: C78.2, R67.2, R68.1, U$59.4 (FB)
PM1GND: C70.2, C71.-, C72.2, C73.2, C74.2, C75.2, C76.2, C77.-, JP37.1, Q6.P$9 (PGND), Q6.P$10 (PGND), Q6.P$11 (PGND), Q6.P$12 (PGND), Q6.P$13 (PGND), R72.1, SJ1.2, TP5.1, TP7.1, U$59.9 (PGND), X7.1, X8.1; also elsewhere on the board
PM1GND2: C80.2, C81.2, C82.2, C83.2, C85.1, R68.2, R74.2, SJ1.1, U$59.16 (AGND), U$59.17 (AGND)
PM1ISNS+: C84.1, R61.2, R76.2, U$59.6 (ISNS+)
PM1ISNS-: C84.2, R64.2, R65.2, R76.1, U$59.5 (ISNS-)
PM1PGOOD: JP51.1, R71.2, TP1.1, U$59.14 (PGOOD)
PM1SS: C81.1, U$59.2 (SS)
PM1VCC: C80.1, R71.1, U$59.10 (VCC)
PM1VIN: C70.1, C71.+, C72.1, JP37.3, R61.1, R62.2, R63.2, R73.2, R77.1, TP4.1, X7.2; also elsewhere on the board
PM1VOUT: C73.1, C74.1, C75.1, C76.1, C77.+, Q6.P$1 (VIN), Q6.P$2 (VIN), R66.1, TP6.1, X8.2; also elsewhere on the board

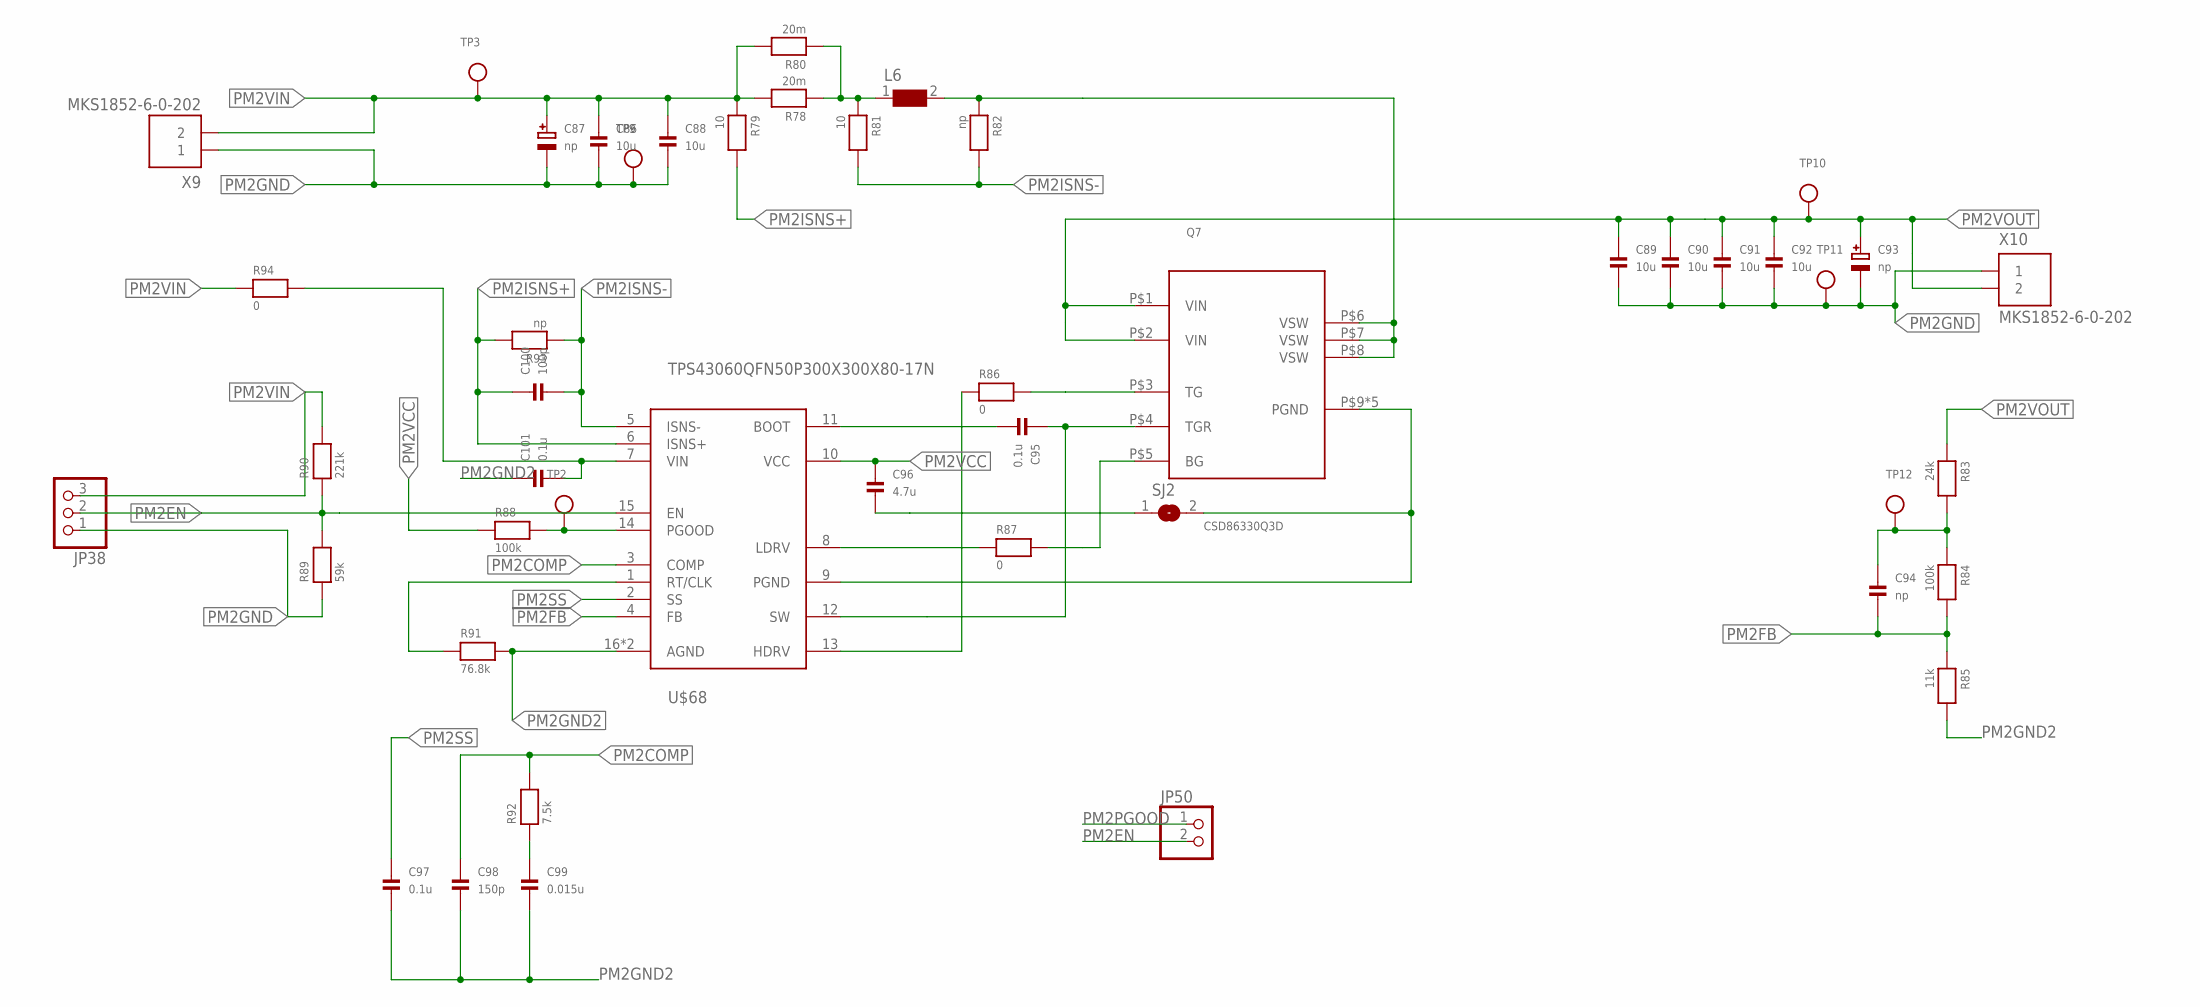
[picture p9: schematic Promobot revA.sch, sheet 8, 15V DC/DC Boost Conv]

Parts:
C86, C88, C89, C90, C91, C92: 10u; 1206
C87, C93: np; CELEC_3.5MM_10MM
C94: np; _0603
C95, C97: 0.1u; _0603
C96: 4.7u; _0603
C98: 150p; _0603
C99: 0.015u; _0603
C100: 100p; _0603MP
C101: 0.1u; _0603MP
JP38: HEADER-1X376MIL; 1X03_ROUND_76
JP50: HEADER-1X2ROUND; 1X02_ROUND
L6: WE-HCI-744311330_7030/7040/7050; WE-HCI_7030/7040/7050
Q7: CSD86330Q3D; SON330X330
R78, R80: 20m; 1206
R79, R81: 10; _0603MP
R82, R93: np; _0603MP
R83: 24k; 0603
R84, R88: 100k; 0603
R85: 11k; 0603
R86, R87, R94: 0; 0603
R89: 59k; 0603
R90: 221k; 0603
R91: 76.8k; 0603
R92: 7.5k; 0603
SJ2: SOLDERJUMPER; SOLDERJUMPER_ARROW_NOPASTE
TP2, TP3, TP9, TP10, TP11, TP12: TESTPOINT0.1"; 1X01_ROUND
U$68: TPS43060QFN50P300X300X80-17N; QFN50P300X300X80-17N
X9, X10: MKS1852-6-0-202

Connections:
unnamed: L6.1, R78.1, R80.1, R81.1
unnamed: L6.2, Q7.P$6 (VSW), Q7.P$7 (VSW), Q7.P$8 (VSW), R82.1
unnamed: C94.1, R83.2, R84.1, TP12.1
unnamed: Q7.P$3 (TG), R86.2
unnamed: R86.1, U$68.13 (HDRV)
unnamed: C95.1, Q7.P$4 (TGR), U$68.12 (SW)
unnamed: C95.2, U$68.11 (BOOT)
unnamed: R87.1, U$68.8 (LDRV)
unnamed: Q7.P$5 (BG), R87.2
unnamed: R91.1, U$68.1 (RT/CLK)
unnamed: C99.1, R92.1
unnamed: C101.2, R94.2, U$68.7 (VIN)
PM2COMP: C98.1, R92.2, U$68.3 (COMP)
PM2EN: JP38.2, JP50.2, R89.2, R90.1, U$68.15 (EN)
PM2FB: C94.2, R84.2, R85.1, U$68.4 (FB)
PM2GND: C86.2, C87.-, C88.2, C89.2, C90.2, C91.2, C92.2, C93.-, JP38.1, Q7.P$9 (PGND), Q7.P$10 (PGND), Q7.P$11 (PGND), Q7.P$12 (PGND), Q7.P$13 (PGND), R89.1, SJ2.2, TP9.1, TP11.1, U$68.9 (PGND), X9.1, X10.1
PM2GND2: C96.2, C97.2, C98.2, C99.2, C101.1, R85.2, R91.2, SJ2.1, U$68.16 (AGND), U$68.17 (AGND)
PM2ISNS+: C100.1, R79.2, R93.2, U$68.6 (ISNS+)
PM2ISNS-: C100.2, R81.2, R82.2, R93.1, U$68.5 (ISNS-)
PM2PGOOD: JP50.1, R88.2, TP2.1, U$68.14 (PGOOD)
PM2SS: C97.1, U$68.2 (SS)
PM2VCC: C96.1, R88.1, U$68.10 (VCC)
PM2VIN: C86.1, C87.+, C88.1, JP38.3, R78.2, R79.1, R80.2, R90.2, R94.1, TP3.1, X9.2
PM2VOUT: C89.1, C90.1, C91.1, C92.1, C93.+, Q7.P$1 (VIN), Q7.P$2 (VIN), R83.1, TP10.1, X10.2

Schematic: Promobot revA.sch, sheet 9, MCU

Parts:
C102, C104, C106, C108, C109, C110: 100n; _0603
C103, C111, C112: 1u; _0603
C105, C107: 22u; EIA3216-18/A-R
C113: 22P; _0603
C114: 22p; _0603
D2: CD1206-S01575; MINIMELF
F1: MF-MSMF050-2 500mA; L1812
J3: USB-MICRO!!!; CON2_USB_MICRO_B_AT
J4: 3x2M; 2X03
JP58: HEADER-1X15; 1X15_ROUND_70
JP59, JP60: HEADER-1X1070MIL; 1X10_ROUND70
JP61: HEADER-1X2ROUND; 1X02_ROUND
L8: MH2029-300Y; 0805
L9: green; CHIPLED_0603
ON: blue; CHIPLED_0603
R95, R100, R103, R104: 10k; _0603
R96, R97, R98, R99, R108, R109: 1k; _0603
R101, R102: 22; _0603
R110: 3k; _0603MP
R111: 1k; _0603MP
RESET: TS42
RX: yellow; CHIPLED_0603
T1: FDN340P/PMV48XP; SOT-23
T2: PMV48XP; SOT-23
TX: yellow; CHIPLED_0603
U9: LP2985-33DBVR; SOT23-DBV
U10: ATMEGA32U4-XUMU; QFN44ML7X7
U11: NCP1117-5; LINEAR_SOT223
X19, X20, X21: MKS1852-6-0-202
Y3: 16MHz KX-7; CRYSTAL-3.2-2.5
Z1, Z2: CG0603MLC-05E; CT/CN0603

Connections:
3V3: C103.1, U9.5 (OUT)
5-GND: RESET.5 (5-GND)
+5V: C104.1, C105.+, C109.1, C110.1, D2.C, J4.2, L8.1, R96.1, R100.2, R108.2, R109.2, T1.2 (S), T2.3 (G), U9.1 (IN), U9.3 (ON/!OFF), U10.2 (UVCC), U10.14 (VCC), U10.24 (AVCC), U10.34 (VCC1), U11.2 (OUT), U11.4 (OUT)
+VIN: C106.1, T2.2 (S), U11.3 (IN)
A0: JP60.1, U10.36 ((ADC7/TDI)PF7)
A1: R110.1, R111.1, U10.37 ((ADC6/TDO)PF6)
A2: JP60.8, U10.38 ((ADC5/TMS)PF5)
A3: JP60.3, U10.39 ((ADC4/TCK)PF4)
A4: JP59.8, U10.40 ((ADC1)PF1)
A5: JP59.3, U10.41 ((ADC0)PF0)
AREF: C108.1, JP61.2, U10.42 (AREF)
AVCC: C112.1, L8.2, U10.44 (AVCC1)
D0/RX: JP59.10, U10.20 ((RXD1/AIN1/INT2)PD2)
D1/TX: JP59.6, U10.21 ((TXD1/INT3)PD3)
D2/SDA: R108.1, U10.19 ((SDA/INT1)PD1), X19.1, X20.1, X21.1
D3/SCL: R109.1, U10.18 ((OC0B/SCL/INT0)PD0), X19.2, X20.2, X21.2
D4*: JP59.5, U10.25 ((ICP1/ADC8)PD4)
D5*: JP59.7, U10.31 ((OC3A/#0C4A)PC6)
D6*: JP60.2, U10.27 ((T0/OC4D/ADC10)PD7)
D7: JP59.1, U10.1 ((INT6/AIN0)PE6)
D+: J3.P3 (D+), R101.2, Z1.1
D-: J3.P2 (D-), R102.2, Z2.1
GND: C102.2, C103.2, C104.2, C105.-, C106.2, C107.-, C108.2, C109.2, C110.2, C111.2, C112.2, C113.1, C114.1, J3.P5 (GND), J3.S1 (SH1), J3.S2 (SH2), J3.S3 (SH3), J3.S4 (SH4), J3.S5 (SH5), J3.S6 (SH6), J4.6, JP61.1, L9.C, ON.C, R95.2, R103.1, R104.1, R111.2, RESET.3, RESET.4, RX.C, TX.C, U9.2 (GND), U10.5 (UGND), U10.15 (GND), U10.23 (GND1), U10.35 (GND2), U10.43 (GND3), U10.EXP (PAD), U11.1 (GND/ADJ), Y3.2 (GND), Y3.4 (GND), Z1.2, Z2.2
HWB: R95.1, U10.33 ((#HWB)PE2)
IO8: JP58.7, U10.28 ((ADC11/PCINT4)PB4)
IO9*: JP60.7, U10.29 ((PCINT5/OC1A/#OC4B/ADC12)PB5)
IO10*: JP58.1, U10.30 ((PCINT6/OC1B/OC4B/ADC13)PB6)
IO11*: JP58.2, U10.12 ((PCINT7/OC0A/OC1C/#RTS)PB7)
IO12*: JP58.6, U10.26 ((T1/#OC4D/ADC9)PD6)
IO13*: JP59.2, R99.1, U10.32 ((ICP3/CLK0/OC4A)PC7)
MISO: J4.1, JP60.10, U10.11 ((PD0/MISO/PCINT3)PB3)
MOSI: J4.4, JP60.6, U10.10 ((PDI/MOSI/PCINT2)PB2)
unnamed: L9.A, R99.2
unnamed: R98.2, RX.A
unnamed: R97.2, TX.A
unnamed: ON.A, R96.2
RD+: R101.1, U10.4 (D+)
RD-: R102.1, U10.3 (D-)
RESET: D2.A, J4.5, R100.1, RESET.1, RESET.2, U10.13 (RESET)
RXLED/SS: JP58.3, JP58.12, JP58.13, JP59.4, JP59.9, JP60.4, JP60.9, R98.1, U10.8 ((SS/PCINT0)PB0)
SCK: J4.3, JP60.5, U10.9 ((SCLK/PCINT1)PB1)
TXLED: JP58.5, R97.1, U10.22 ((XCK1/#CTS)PD5)
UCAP: C111.1, U10.6 (UCAP)
VBAT: JP58.4, R110.2
VIN: R104.2, T1.3 (G), T2.1 (D)
VUSB: C102.1, F1.2, R103.2, T1.1 (D), U10.7 (VBUS)
VUSBD: C107.+, F1.1, J3.P1 (VBUS)
XTAL1: C113.2, U10.17 (XTAL1), Y3.3 (C2)
XTAL2: C114.2, U10.16 (XTAL2), Y3.1 (C1)

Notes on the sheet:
+5V REG
ICSP
USB
+5V SELECTOR (USB)
+3V3 REG
#PWM 8bit
#PWM Hi-Speed
#PWM 16bit
#PWM 10bit
#PWM 8/16bit
Vlotage divider

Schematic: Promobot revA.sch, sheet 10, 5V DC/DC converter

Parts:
C115, C118: 0.1u; _0603
C116, C117: 10u; 1206
C119, C120, C121: 22u; 1206
JP44, JP45: HEADER-1X376MIL; 1X03_ROUND_76
JP57: HEADER-1X2ROUND; 1X02_ROUND
L7: WE-HCI-744311330_7030/7040/7050; WE-HCI_7030/7040/7050
R105, R107: 10k; _0603
R106: 54.9k; _0603
U12: TPS563200; SOT95P280X145-6N

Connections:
unnamed: R105.1, U12.5 (EN)
unnamed: R106.2, R107.1, U12.4 (VFB)
unnamed: C118.1, L7.1, U12.2 (SW)
unnamed: C118.2, U12.6 (VBST)
PM3EN: R105.2; also elsewhere on the board
PM3GND: C115.2, C116.2, C117.2, C119.2, C120.2, C121.2, JP44.1, JP45.1, JP57.1, R107.2, U12.1 (GND); also elsewhere on the board
PM3VIN: C115.1, C116.1, C117.1, JP57.2, U12.3 (VIN); also elsewhere on the board
PM3VOUT: C119.1, C120.1, C121.1, JP44.2, JP45.2, L7.2, R106.1
PPM1: JP44.3; also elsewhere on the board
PPM2: JP45.3; also elsewhere on the board

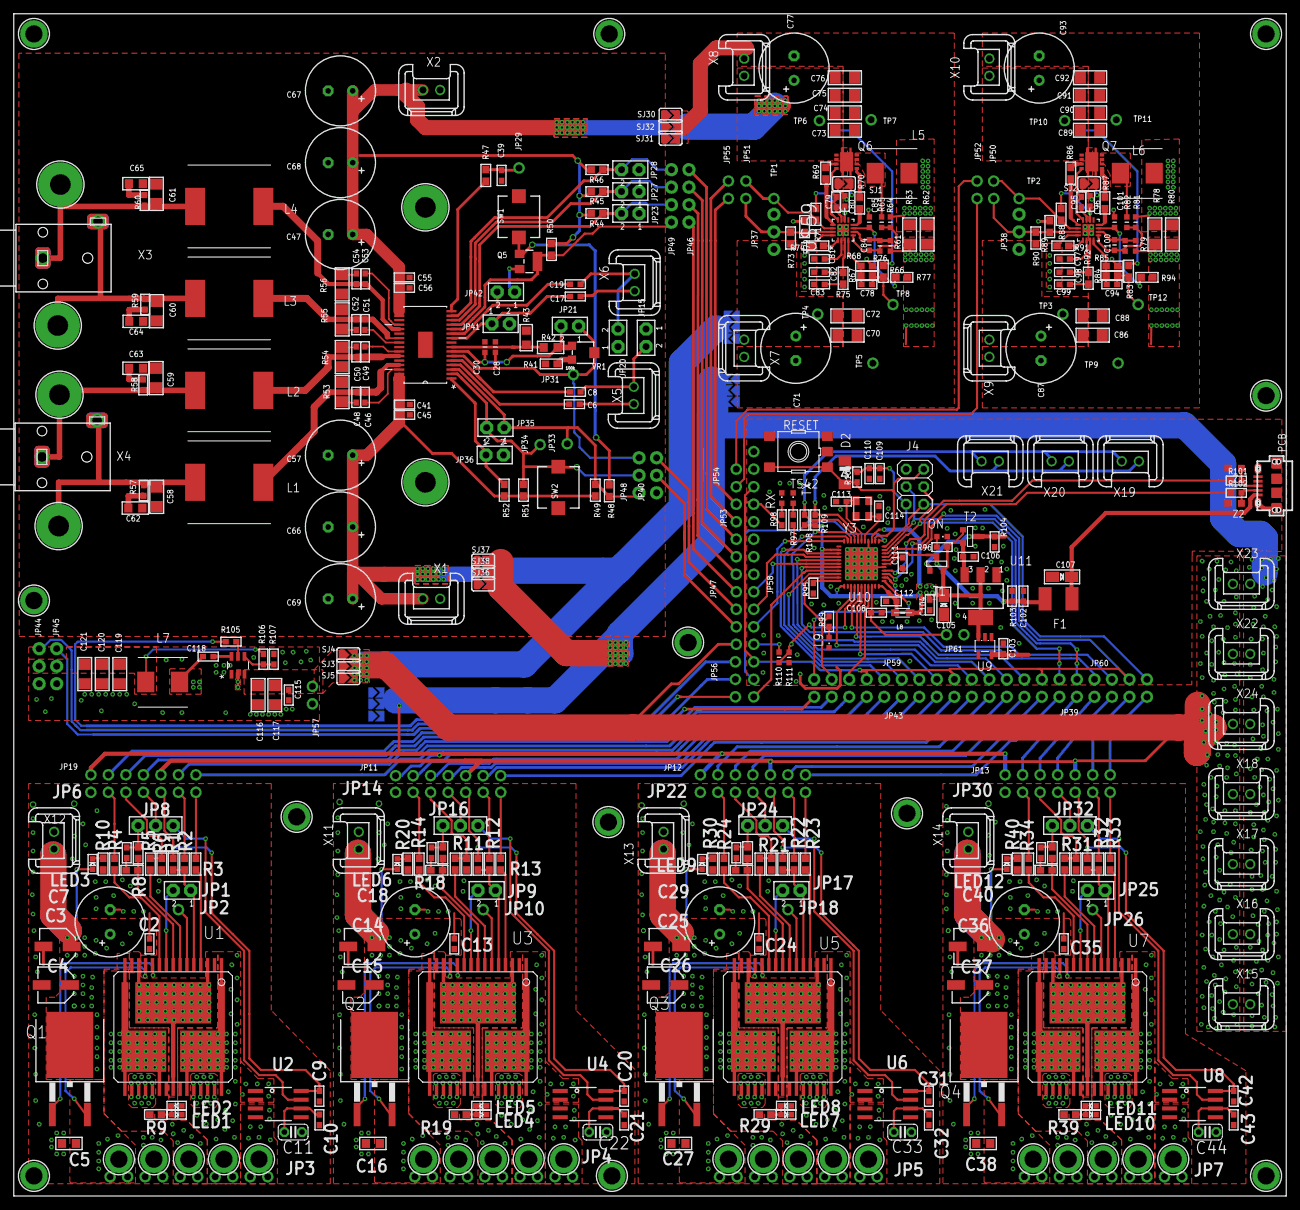
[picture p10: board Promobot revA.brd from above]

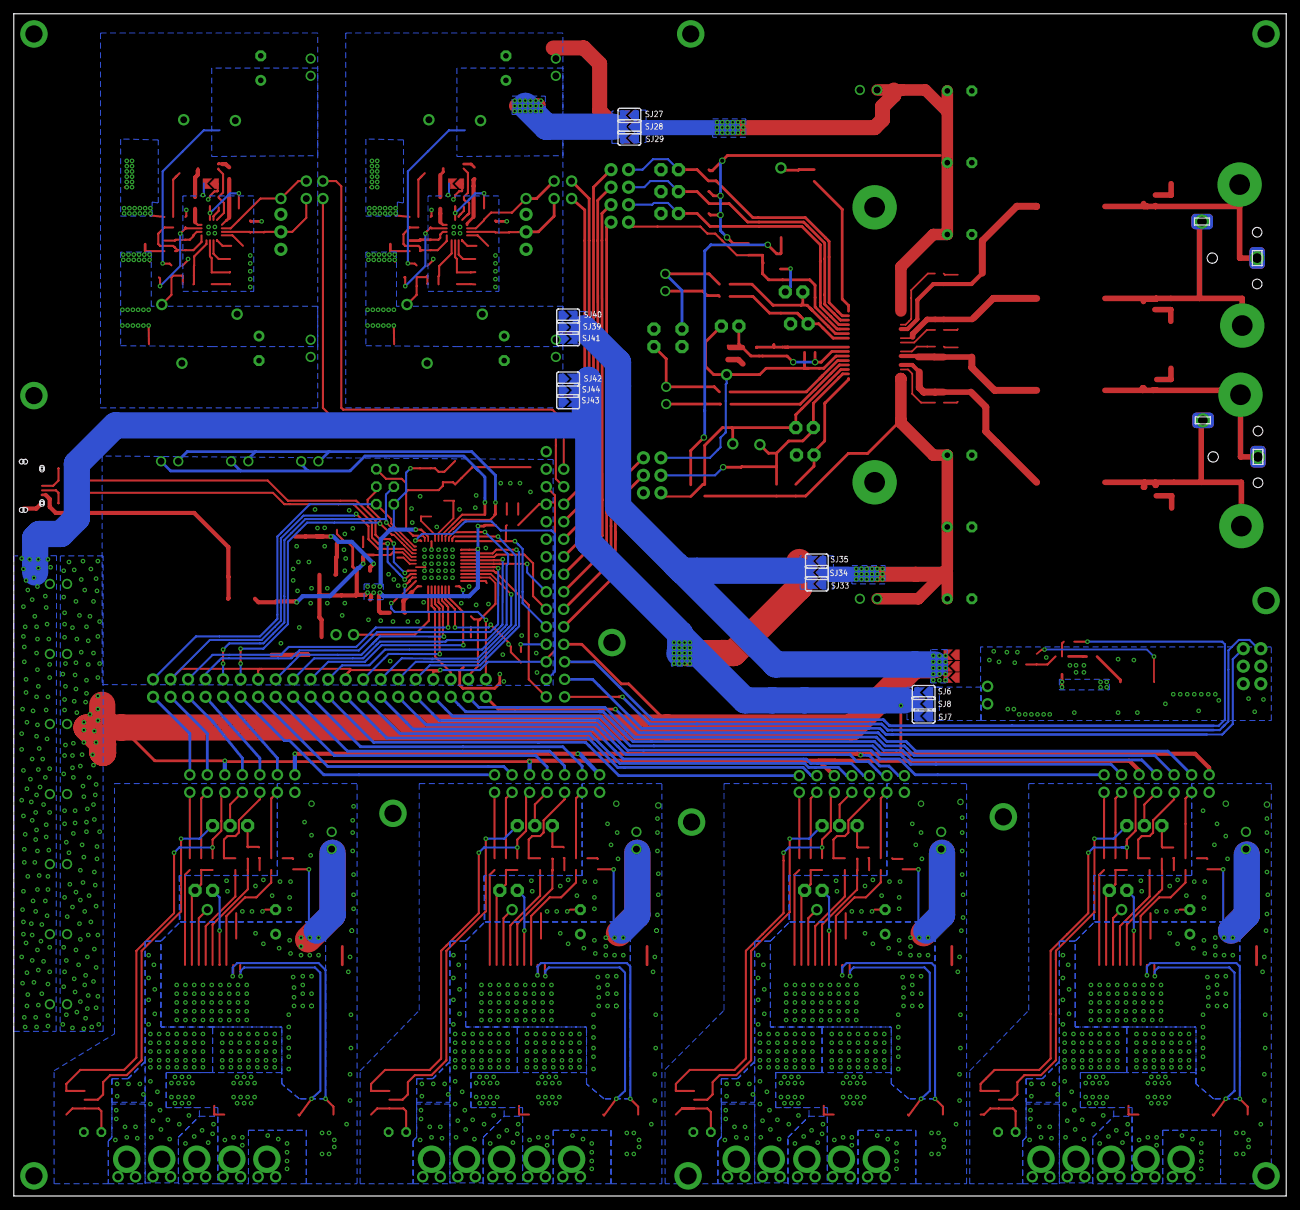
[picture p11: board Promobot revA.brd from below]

Board: 2 copper layers, 184.5 x 171.4 mm, 452 parts (15 on the bottom side), 282 nets.

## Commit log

2014-12-31 Add Eagle files
    add .sch and .brd files
    [Promobot revA.brd, Promobot revA.sch]
2015-01-14 Add voltage divider
    R110, R111 - voltage divider. Connected to A5 pin
    [Promobot revA.brd, Promobot revA.sch]

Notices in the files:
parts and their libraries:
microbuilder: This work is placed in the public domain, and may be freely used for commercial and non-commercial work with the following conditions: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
